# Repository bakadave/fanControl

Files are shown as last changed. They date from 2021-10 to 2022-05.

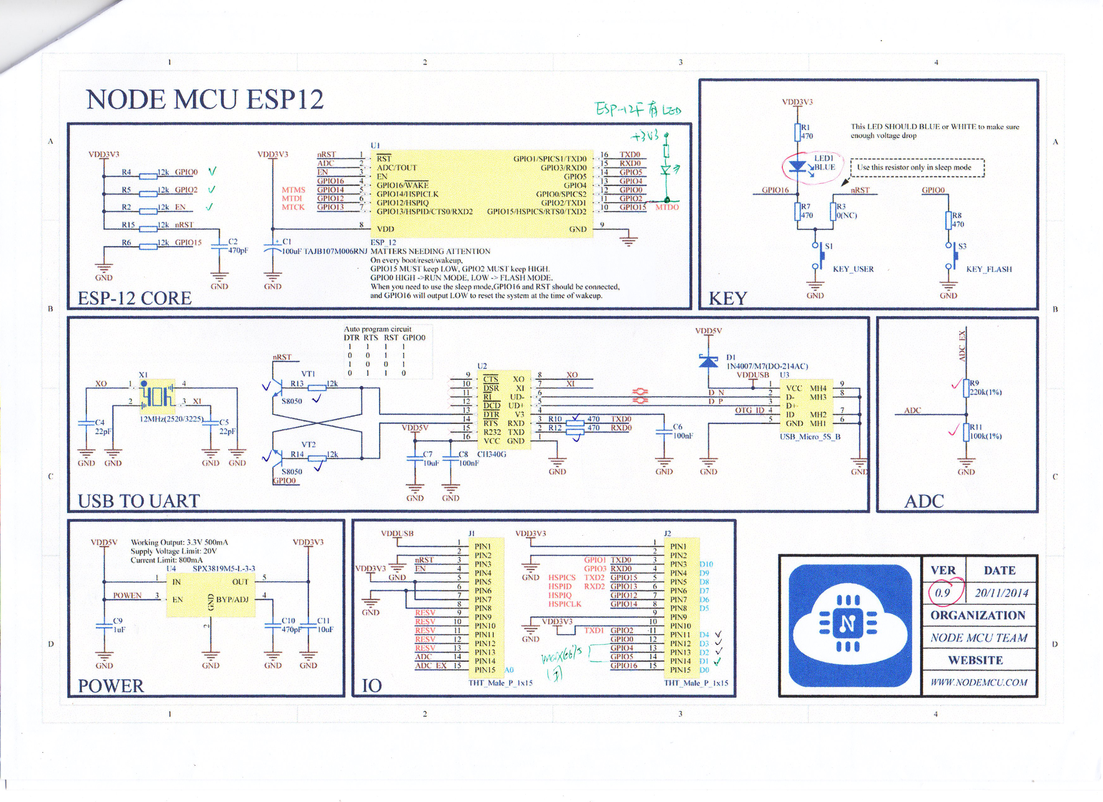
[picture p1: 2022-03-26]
PCB/fanControl/notes/esp12e-devkit-v2-xiaolaba-schematic_3.jpg

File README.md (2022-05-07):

# fanControl readme

## EEPROM memory map

| memory location | data type | Description|
| --- | --- | --- |
| 1 | bool | WiFi on |
| 2 | bool | 5V PSU |
| 3 | bool | USB sense |
| 4 | float | cal_a |
| 5 |  | cal_a |
| 6 |  | cal_a |
| 7 |  | cal_a |
| 8 | float | cal_b |
| 9 |  | cal_b |
| 10 | | cal_b |
| 11 | | cal_b |
| 12 | char[16] | hostname |
| 13 | | hostname |
| 14 | | hostname |
| 15 | | hostname |
| 16 | | hostname |
| 17 | | hostname |
| 18 | | hostname |
| 19 | | hostname |
| 20 | | hostname |
| 21 | | hostname |
| 22 | | hostname |
| 23 | | hostname |
| 24 | | hostname |
| 25 | | hostname |
| 26 | | hostname |
| 27 | | hostname |
| 28 | N/A | unused |
| 29 | N/A | unused |
| 30 | N/A | unused |
| 31 | N/A | unused |
| 32 | N/A | unused |

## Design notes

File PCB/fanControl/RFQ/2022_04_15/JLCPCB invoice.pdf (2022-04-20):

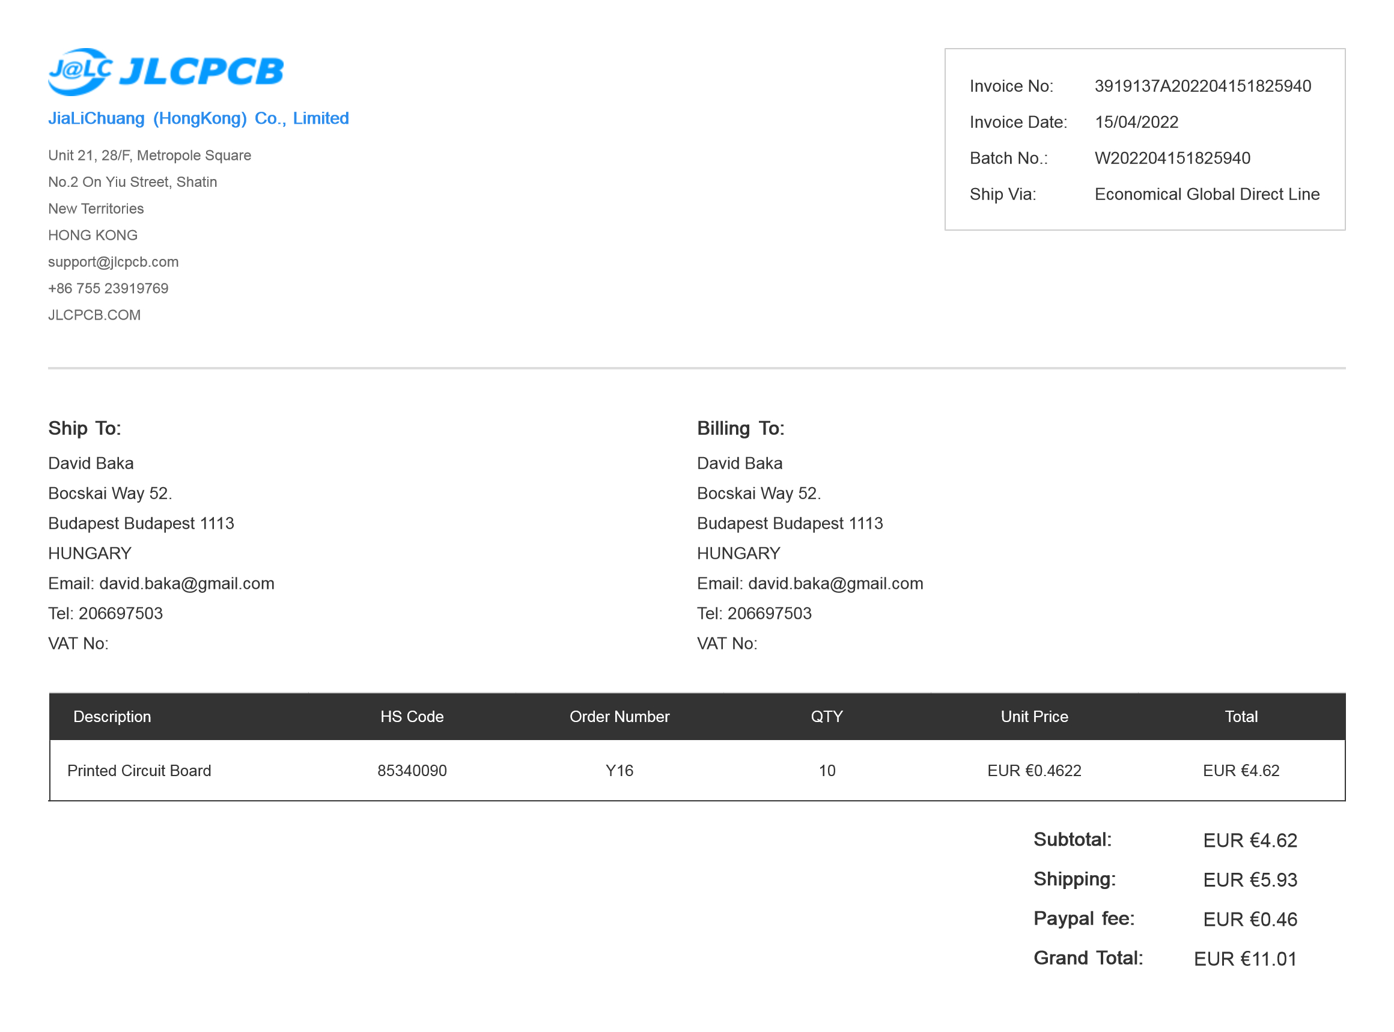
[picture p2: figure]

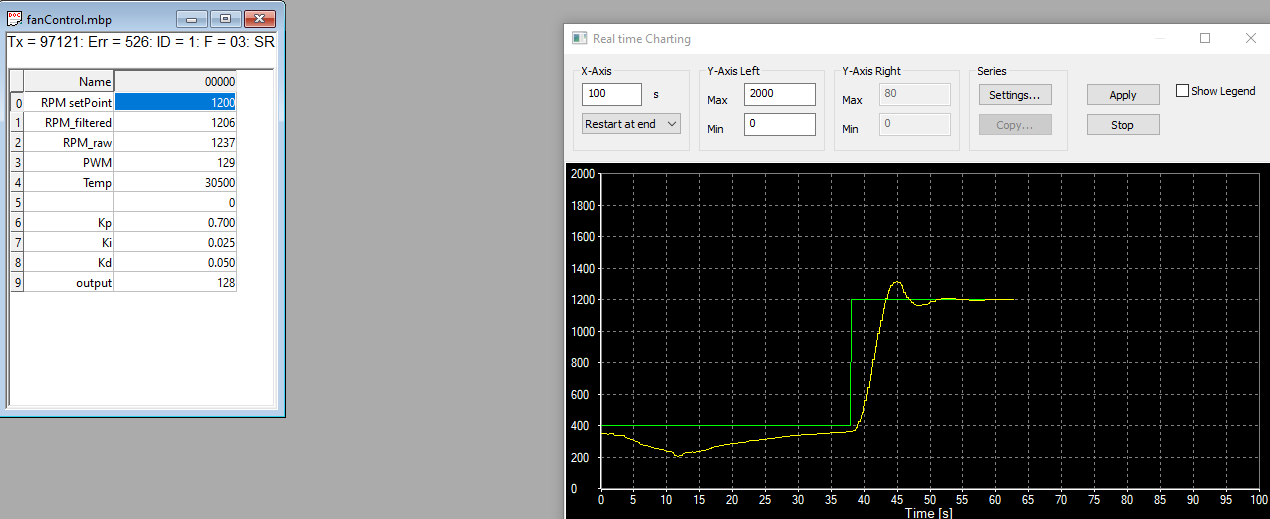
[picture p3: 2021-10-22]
notes/Screenshot_8.png

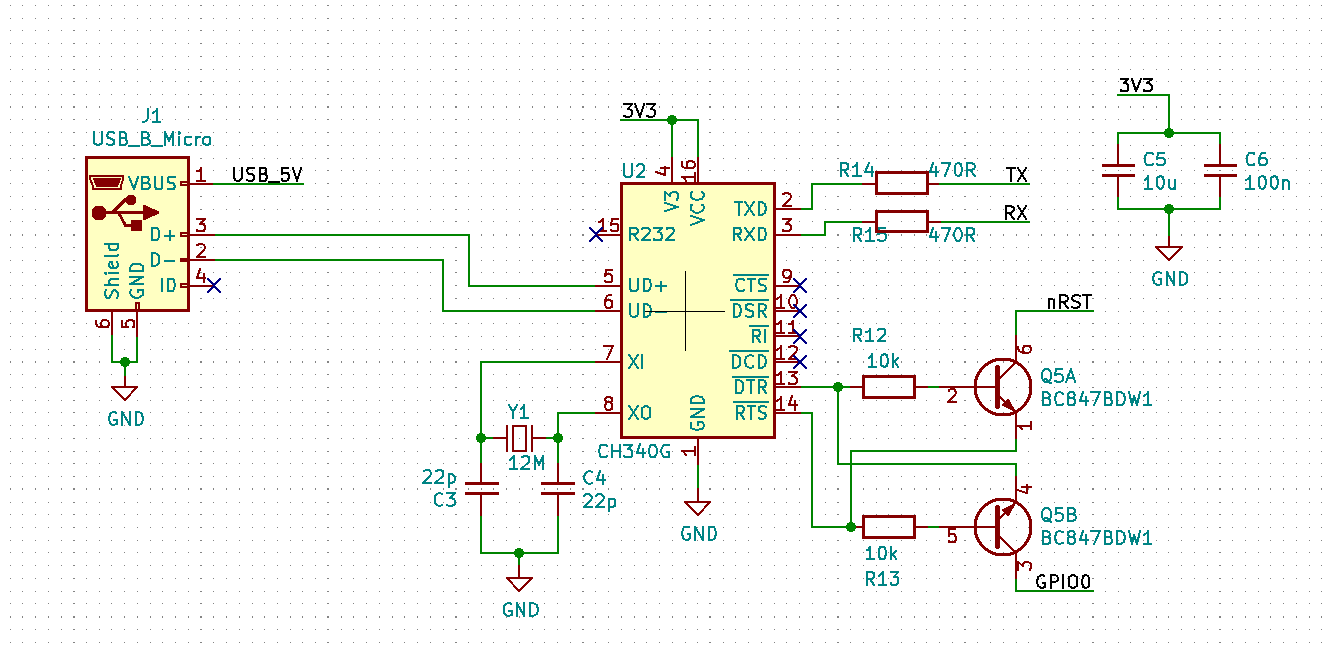
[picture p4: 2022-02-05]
PCB/fanControl/notes/CH340G.png

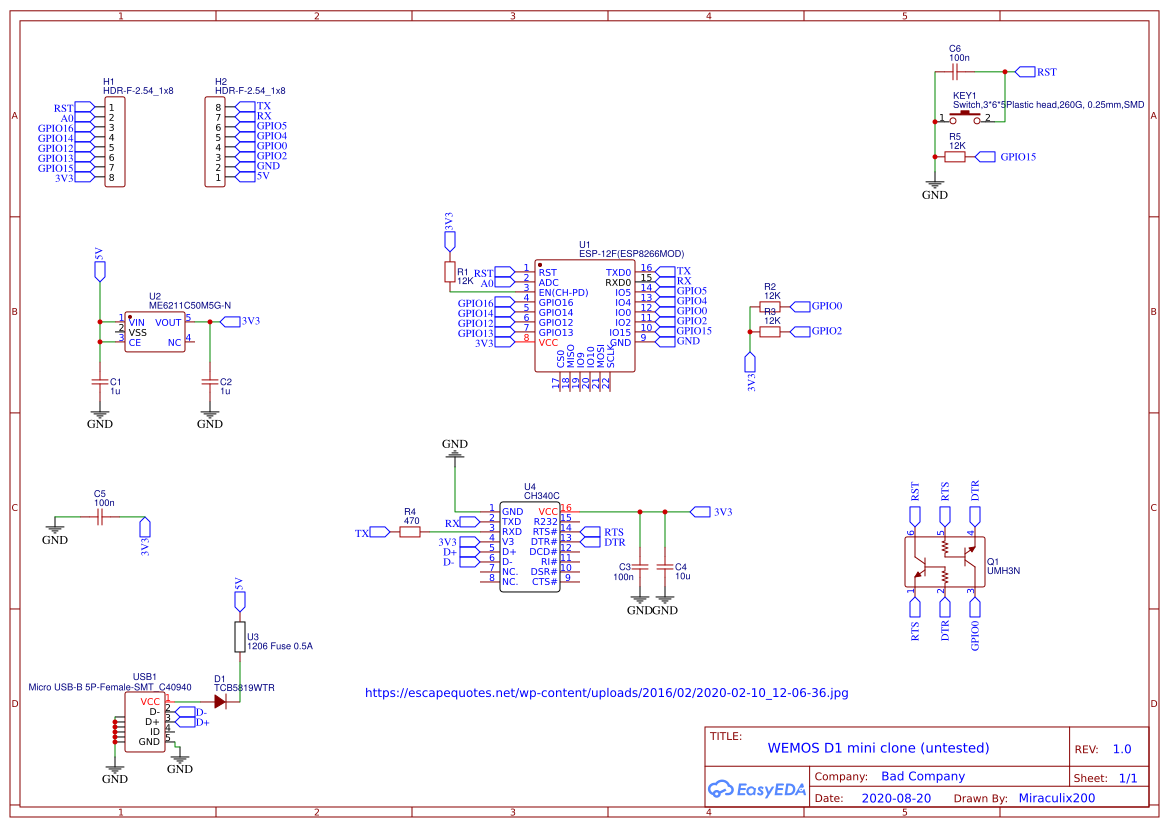
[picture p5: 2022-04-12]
PCB/fanControl/notes/Wemos D1 Mini.png

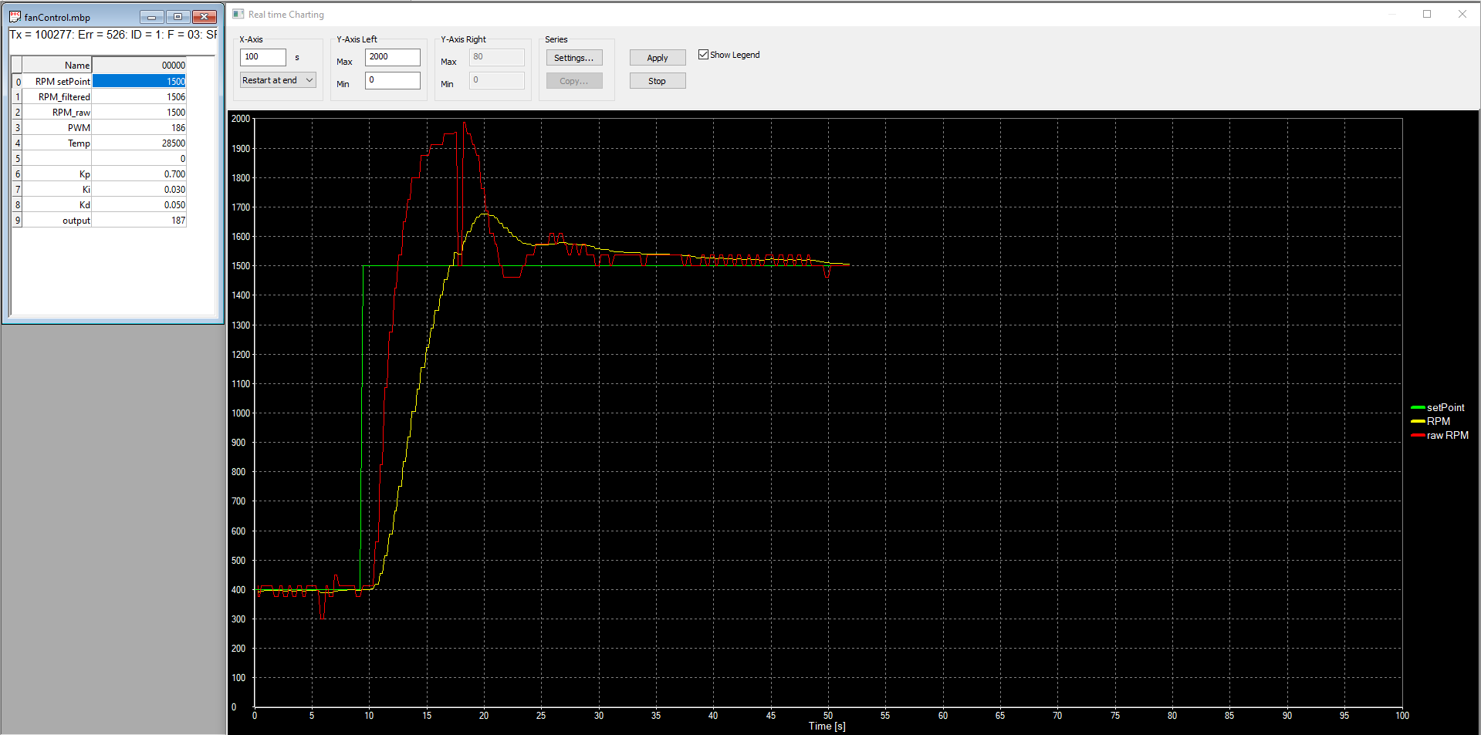
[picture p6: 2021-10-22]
notes/Screenshot_1.png

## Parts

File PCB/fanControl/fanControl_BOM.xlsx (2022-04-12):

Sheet: fanControl_BOM
Reference | Quantity | Value | Footprint | Datasheet | LCSC | MPN | Manufacturer | Supplier | URL | LCSC order quant | # available | 5
C1 C3 | 2 | 22p | agro-footprint:CAP_0805 | https://datasheet.lcsc.com/lcsc/2006151142_YAGEO-CC0805FRNPO9BN220_C541515.pdf | C541515 | CC0805FRNPO9BN220 | Yageo | LCSC |  | 10 | 10
C12 | 1 | 10u 10V | Capacitor_Tantalum_SMD:CP_EIA-3216-18_Kemet-A_Pad1.58x1.35mm_HandSolder | https://datasheet.lcsc.com/lcsc/2011031906_KEMET-T529P106M010AAE200_C696821.pdf | C696821 | T529P106M010AAE200 | KEMET | LCSC |  | 5 | 5
C2 | 1 | 10n 50V | agro-footprint:CAP_0805 | https://datasheet.lcsc.com/lcsc/2005262134_YAGEO-CC0805JKNPO9BN103_C527201.pdf | C527201 | CC0805JKNPO9BN103 | Yageo | LCSC |  | 5 | 4
C4 | 1 | 47u | Capacitor_THT:C_Radial_D6.3mm_H11.0mm_P2.50mm |  |  |  |  | Ã rwill | https://arwill.hu/termekek/passziv-alkatreszek/kondenzatorok/elektrolit-85c-105c/47uf-50v-elektrolit-kondenzator-974067/ | 5
C5 | 1 | 10u | agro-footprint:CAP_0805 | https://datasheet.lcsc.com/lcsc/1810311438_YAGEO-CC0805ZKY5V6BB106_C88484.pdf | C88484 | CC0805ZKY5V6BB106 | Yageo | LCSC |  | 5 | 49
C6 C7 C10 C11 | 4 | 100n | agro-footprint:CAP_0805 | https://datasheet.lcsc.com/lcsc/1810101813_YAGEO-CC0805KRX7R9BB104_C49678.pdf | C49678 | CC0805KRX7R9BB104 | Yageo | LCSC |  | 20 | 47
C8 | 1 | 470u | Capacitor_THT:C_Radial_D8.0mm_H11.5mm_P3.50mm |  |  |  |  | Ã rwill | https://arwill.hu/termekek/passziv-alkatreszek/kondenzatorok/elektrolit-85c-105c/470uf-16v-elektrolit-kondenzator-229671/ | 5 | 7
C9 | 1 | 100u | Capacitor_SMD:C_1206_3216Metric | https://datasheet.lcsc.com/lcsc/2006191032_YAGEO-CC1206MKX5R5BB107_C110048.pdf | C110048 | CC1206MKX5R5BB107 | Yageo | LCSC |  | 5 | 5
D1 | 1 | SMCJ36CA | Diode_SMD:D_SMC | https://datasheet.lcsc.com/lcsc/2110190930_BOURNS-SMCJ36CA_C2831485.pdf | C2831485 | SMCJ36CA | Bourns | LCSC |  | 5 | 4
D2 | 1 | BZX84C10L | Diode_SMD:D_SOT-23_ANK | https://datasheet.lcsc.com/lcsc/1810301517_onsemi-BZX84C10LT1G_C82476.pdf | C82476 | BZX84C10LT1G | onsemi | LCSC |  | 5 | 9
D3 D5 | 2 | MMSZ3V0 | Diode_SMD:D_SOD-123 | https://datasheet.lcsc.com/lcsc/1807270934_Tak-Cheong-MMSZ3V0CW_C248751.pdf | C248751 | MMSZ3V0CW | Tak Cheong | LCSC |  | 10 | 48
D4 | 1 | BZX84C6V8L | Diode_SMD:D_SOT-23_ANK | https://datasheet.lcsc.com/lcsc/1810301513_onsemi-BZX84C6V8LT1G_C90848.pdf | C90848 | BZX84C6V8LT1G | onsemi | LCSC |  | 5 | 9
D6 | 1 | RB160M | Diode_SMD:D_SOD-123 | https://datasheet.lcsc.com/lcsc/1810131621_ROHM-Semicon-RB160M-40TR_C123003.pdf | C123003 | RB160MM-40TR | Rohm Semiconductor | LCSC |  | 5 | 4
D7 | 1 | 10BQ015 | Diode_SMD:D_SMB | https://datasheet.lcsc.com/lcsc/2001101209_Vishay-Intertech-VS-10BQ015-M3-5BT_C413466.pdf | C413466 | VS-10BQ015-M3/5BT | Vishay | LCSC |  | 5 | 4
D8 | 1 | LED | agro-footprint:LED_0805 | https://datasheet.lcsc.com/lcsc/1811131731_Everlight-Elec-17-215-BHC-AP1Q2-3T_C131208.pdf | C131208 | 17-215/BHC-AP1Q2/3T | Everlight Elec | LCSC |  | 5 | 10
J1 | 1 | USB_B_Micro | Connector_USB:USB_Micro-B_Molex-105017-0001 | https://datasheet.lcsc.com/lcsc/1811131824_MOLEX-1050170001_C136000.pdf | C136000 | 1050170001 | Molex | LCSC |  | 5 | 4
J2 | 1 | Barrel_Jack_Switch | fanControl:BarrelJack_Wuerth_6941xx301002 |  |  |  |  | Ã rwill | https://arwill.hu/termekek/csatlakozok/tap/dc/dc-tap-aljzat-5-5-2-1-586196/ | 5
L1 | 1 | 470u | Inductor_THT:L_Radial_D10.5mm_P5.00mm_Abacron_AISR-01 |  |  |  |  | Ã rwill | https://arwill.hu/termekek/passziv-alkatreszek/induktivitasok/radialis/470uh-1-2a-induktivitas-659003/ | 5
Q1 | 1 | FDD4243 | fanControl:TO-252-2_TabPin5 | https://datasheet.lcsc.com/lcsc/2007231308_VBsemi-Elec-FDD4243_C709958.pdf | C709958 | FDD4243 | VBsemi Elec | LCSC |  | 5 | 4
Q2 Q5 | 2 | BSS169 | Package_TO_SOT_SMD:SOT-23 | https://datasheet.lcsc.com/lcsc/1810261812_Infineon-Technologies-BSS169H6327_C83053.pdf | C83053 | BSS169H6327 | Infineon | LCSC |  | 10 | 7
Q4 | 1 | BC847BDW1 | Package_TO_SOT_SMD:SOT-363_SC-70-6 | https://datasheet.lcsc.com/lcsc/1810010214_onsemi-BC847BDW1T1G_C82368.pdf | C82368 | BC847BDW1T1G | onsemi | LCSC |  | 5 | 9
Q6 | 1 | BRCS4484 | fanControl:BRCS4484 | https://datasheet.lcsc.com/lcsc/2012021739_Foshan-Blue-Rocket-Elec-BRCS4484SC_C914060.pdf | C914060 | BRCS4484SC | Foshan Blue Rocket Elec | LCSC |  | 5 | 5
R1 R2 R14 R20 R29 R31 R32 | 7 | 1k | agro-footprint:RES_0805 | https://datasheet.lcsc.com/lcsc/1810010217_YAGEO-RC0805JR-071KL_C100046.pdf | C100046 | RC0805JR-071KL | Yageo | LCSC |  | 35 | 98
R12 R13 R26 R27 R28 | 5 | 470R | agro-footprint:RES_0805 | https://datasheet.lcsc.com/lcsc/1810162110_YAGEO-RC0805JR-07470RL_C114747.pdf | C114747 | RC0805JR-07470RL | Yageo | LCSC |  | 25 | 95
R16 | 1 | 3k6 | agro-footprint:RES_0805 | https://datasheet.lcsc.com/lcsc/1810311331_YAGEO-AC0805JR-073K6L_C229201.pdf | C229201 | AC0805JR-073K6L | Yageo | LCSC |  | 5 | 49
R17 | 1 | 6k8 | agro-footprint:RES_0805 | https://datasheet.lcsc.com/lcsc/1810311425_YAGEO-RC0805JR-076K8L_C137409.pdf | C137409 | RC0805JR-076K8L | Yageo | LCSC |  | 5 | 99
R18 | 1 | 1k1 1% | agro-footprint:RES_0805 | https://datasheet.lcsc.com/lcsc/1810241428_YAGEO-RC0805FR-071K1L_C185294.pdf | C185294 | RC0805FR-071K1L | Yageo | LCSC |  | 5 | 100
R19 | 1 | 3k3 1% | agro-footprint:RES_0805 | https://datasheet.lcsc.com/lcsc/1810311430_YAGEO-RC0805FR-073K3L_C114531.pdf | C114531 | RC0805FR-073K3L | Yageo | LCSC |  | 5 | 100
R3 R15 R30 R33 | 4 | 100k | agro-footprint:RES_0805 | https://datasheet.lcsc.com/lcsc/1810241513_YAGEO-RC0805JR-07100KL_C100049.pdf | C100049 | RC0805JR-07100KL | Yageo | LCSC |  | 20 | 99
R4 R7 R8 R10 R11 R21 R22 R23 R24 R25 | 10 | 10k | agro-footprint:RES_0805 | https://datasheet.lcsc.com/lcsc/1810171610_YAGEO-RC0805JR-0710KL_C100047.pdf | C100047 | RC0805JR-0710KL | Yageo | LCSC |  | 50 | 93
R5 | 1 | 2k2 | agro-footprint:RES_0805 | https://datasheet.lcsc.com/lcsc/1810311425_YAGEO-RC0805JR-072K2L_C114237.pdf | C114237 | RC0805JR-072K2L | Yageo | LCSC |  | 5 | 99
R6 | 1 | 4k7 | agro-footprint:RES_0805 | https://datasheet.lcsc.com/lcsc/1810010620_YAGEO-RC0805JR-074K7L_C105427.pdf | C105427 | RC0805JR-074K7L | Yageo | LCSC |  | 5 | 99
R9 | 1 | 47k | agro-footprint:RES_0805 | https://datasheet.lcsc.com/lcsc/1810311310_YAGEO-RC0805JR-0747KL_C131051.pdf | C131051 | RC0805JR-0747KL | Yageo | LCSC |  | 5 | 100
RV1 | 1 | 1k | fanControl:pot | https://datasheet.lcsc.com/lcsc/1810170727_HDK-Hokuriku-Elec-Industry-VG039NCHXTB102_C128543.pdf | C128543 | VG039NCHXTB102 | HDK | LCSC |  | 5 | 9
U2 | 1 | CH340B | Package_SO:SOIC-16_3.9x9.9mm_P1.27mm | https://www.mpja.com/download/35227cpdata.pdf | C81010 | CH340B | WCH | LCSC |  | 5 | 2
U3 | 1 | LM2575BT-ADJ | Package_TO_SOT_THT:TO-220-5_Vertical | https://datasheet.lcsc.com/lcsc/1912111437_HGSEMI-LM2575T-ADJ_C434579.pdf | C434579 | LM2575T-ADJ | HGSEMI | LCSC |  | 5 | 5
U4 | 1 | LM1117 | Package_TO_SOT_SMD:SOT-223-3_TabPin2 | https://datasheet.lcsc.com/lcsc/1809301716_Texas-Instruments-LM1117IMPX-3-3-NOPB-_C23984.pdf | C23984 | LM1117IMPX-3.3/NOPB | Texas Instruments | LCSC |  | 5 | 4
U5 | 1 | ESP-12E | kicad-ESP8266:ESP-12E | http://l0l.org.uk/2014/12/esp8266-modules-hardware-guide-gotta-catch-em-all/ | C89297 | ESP-12E | Ai-Thinker | LCSC |  | 5 | 4
Y1 | 1 | 12M | Crystal:Crystal_SMD_3225-4Pin_3.2x2.5mm | https://datasheet.lcsc.com/lcsc/1912111437_JGHC-S3212000101080_C390763.pdf | C390763 | S3212000101080 | JGHC | LCSC |  | 5

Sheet: SMT selected
Comment | Designator | Footprint | JLCPCB Part #
10k | R7,R8,R13 | agro-footprint:RES_0805 | C17414
6k8 | R3,R12 | agro-footprint:RES_0805 | C17772
100n | C10,C11 | agro-footprint:CAP_0805 | C49678
10u10V | C12 | Capacitor_Tantalum_SMD:CP_EIA-3216-18_Kemet-A_Pad1.58x1.35mm_HandSolder | C7171
100u | C9 | Capacitor_SMD:C_1206_3216Metric | C15008
2k | R4 | agro-footprint:RES_0805 | C17604
47k | R11 | agro-footprint:RES_0805 | C17713
1k | R1,R9,R20,R29,R30,R32,R18 | agro-footprint:RES_0805 | C17513
3k31% | R19 | agro-footprint:RES_0805 | C26010
100k | R2,R10,R31,R33 | agro-footprint:RES_0805 | C149504
470R | R26,R28 | agro-footprint:RES_0805 | C17710

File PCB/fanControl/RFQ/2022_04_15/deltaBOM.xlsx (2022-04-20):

Reference | Quantity | Value | Footprint | Datasheet | LCSC | MPN | Manufacturer | Supplier | RMK | # needed | # available | delta
C10 C12 | 2 | 10u 10V | Capacitor_Tantalum_SMD:CP_EIA-3216-18_Kemet-A_Pad1.58x1.35mm_HandSolder | https://datasheet.lcsc.com/lcsc/2011031906_KEMET-T529P106M010AAE200_C696821.pdf | C696821 | T529P106M010AAE200 | KEMET | LCSC |  | 8 | 5 | -3
C2 C13 C14 | 3 | 10n 50V | agro-footprint:CAP_0805 | https://datasheet.lcsc.com/lcsc/2005262134_YAGEO-CC0805JKNPO9BN103_C527201.pdf | C527201 | CC0805JKNPO9BN103 | Yageo | LCSC |  | 12 | 4 | -8
D3 D5 | 2 | BZX84C3V3 | Diode_SMD:D_SOT-23_ANK | https://datasheet.lcsc.com/lcsc/1810301522_onsemi-BZX84C3V3LT1G_C82473.pdf | C82473 | BZX84C3V3LT1G | onsemi | LCSC |  | 8 | #N/A | -8
D9 | 1 | CUS10S30 | Diode_SMD:D_SOD-323_HandSoldering | https://datasheet.lcsc.com/lcsc/1810181811_TOSHIBA-CUS10S30-H3F_C146335.pdf | C146335 | CUS10S30,H3F | Toshiba | LCSC |  | 4 | #N/A | -4
Q2 Q8 | 2 | BSS84 | Package_TO_SOT_SMD:SOT-23 | https://datasheet.lcsc.com/lcsc/1808281643_Infineon-Technologies-BSS84PH6327_C152212.pdf | C152212 | BSS84PH6327 | Infineon | LCSC |  | 8 | #N/A | -8
Q4 Q5 Q7 Q9 Q10 | 5 | BC847B | Package_TO_SOT_SMD:SOT-23 | https://datasheet.lcsc.com/lcsc/1810301520_onsemi-BC847BLT1G_C94393.pdf | C94393 | BC847BLT1G | onsemi | LCSC |  | 20 | #N/A | -20
Q6 | 1 | DMP4065 | Package_TO_SOT_SMD:SOT-23 | https://datasheet.lcsc.com/lcsc/1912111437_Diodes-Incorporated-DMP4065S-7_C182476.pdf | C182476 | DMP4065S-7 | Diodes Incorporated | LCSC |  | 4 | #N/A | -4
R2 R4 R14 R40 | 4 | 22k | agro-footprint:RES_0805 | https://datasheet.lcsc.com/lcsc/1810311430_YAGEO-RC0805FR-0722KL_C114565.pdf | C114565 | RC0805FR-0722KL | Yageo | LCSC | 1% | 16 | #N/A | -16
R36 | 1 | 6k8 | agro-footprint:RES_0805 | https://datasheet.lcsc.com/lcsc/1810311431_YAGEO-RC0805FR-076K8L_C114550.pdf | C114550 | RC0805FR-076K8L | Yageo | LCSC | 1% | 4 | #N/A | -4
R6 R10 R11 | 3 | 4k7 | agro-footprint:RES_0805 | https://datasheet.lcsc.com/lcsc/1810161341_YAGEO-RC0805FR-074K7L_C60816.pdf | C60816 | RC0805FR-074K7L | Yageo | LCSC | 1% | 12 | #N/A | -12
U2 | 1 | CH340B | Package_SO:SOIC-16_3.9x9.9mm_P1.27mm | https://www.mpja.com/download/35227cpdata.pdf | C81010 | CH340B | WCH | LCSC |  | 4 | 2 | -2

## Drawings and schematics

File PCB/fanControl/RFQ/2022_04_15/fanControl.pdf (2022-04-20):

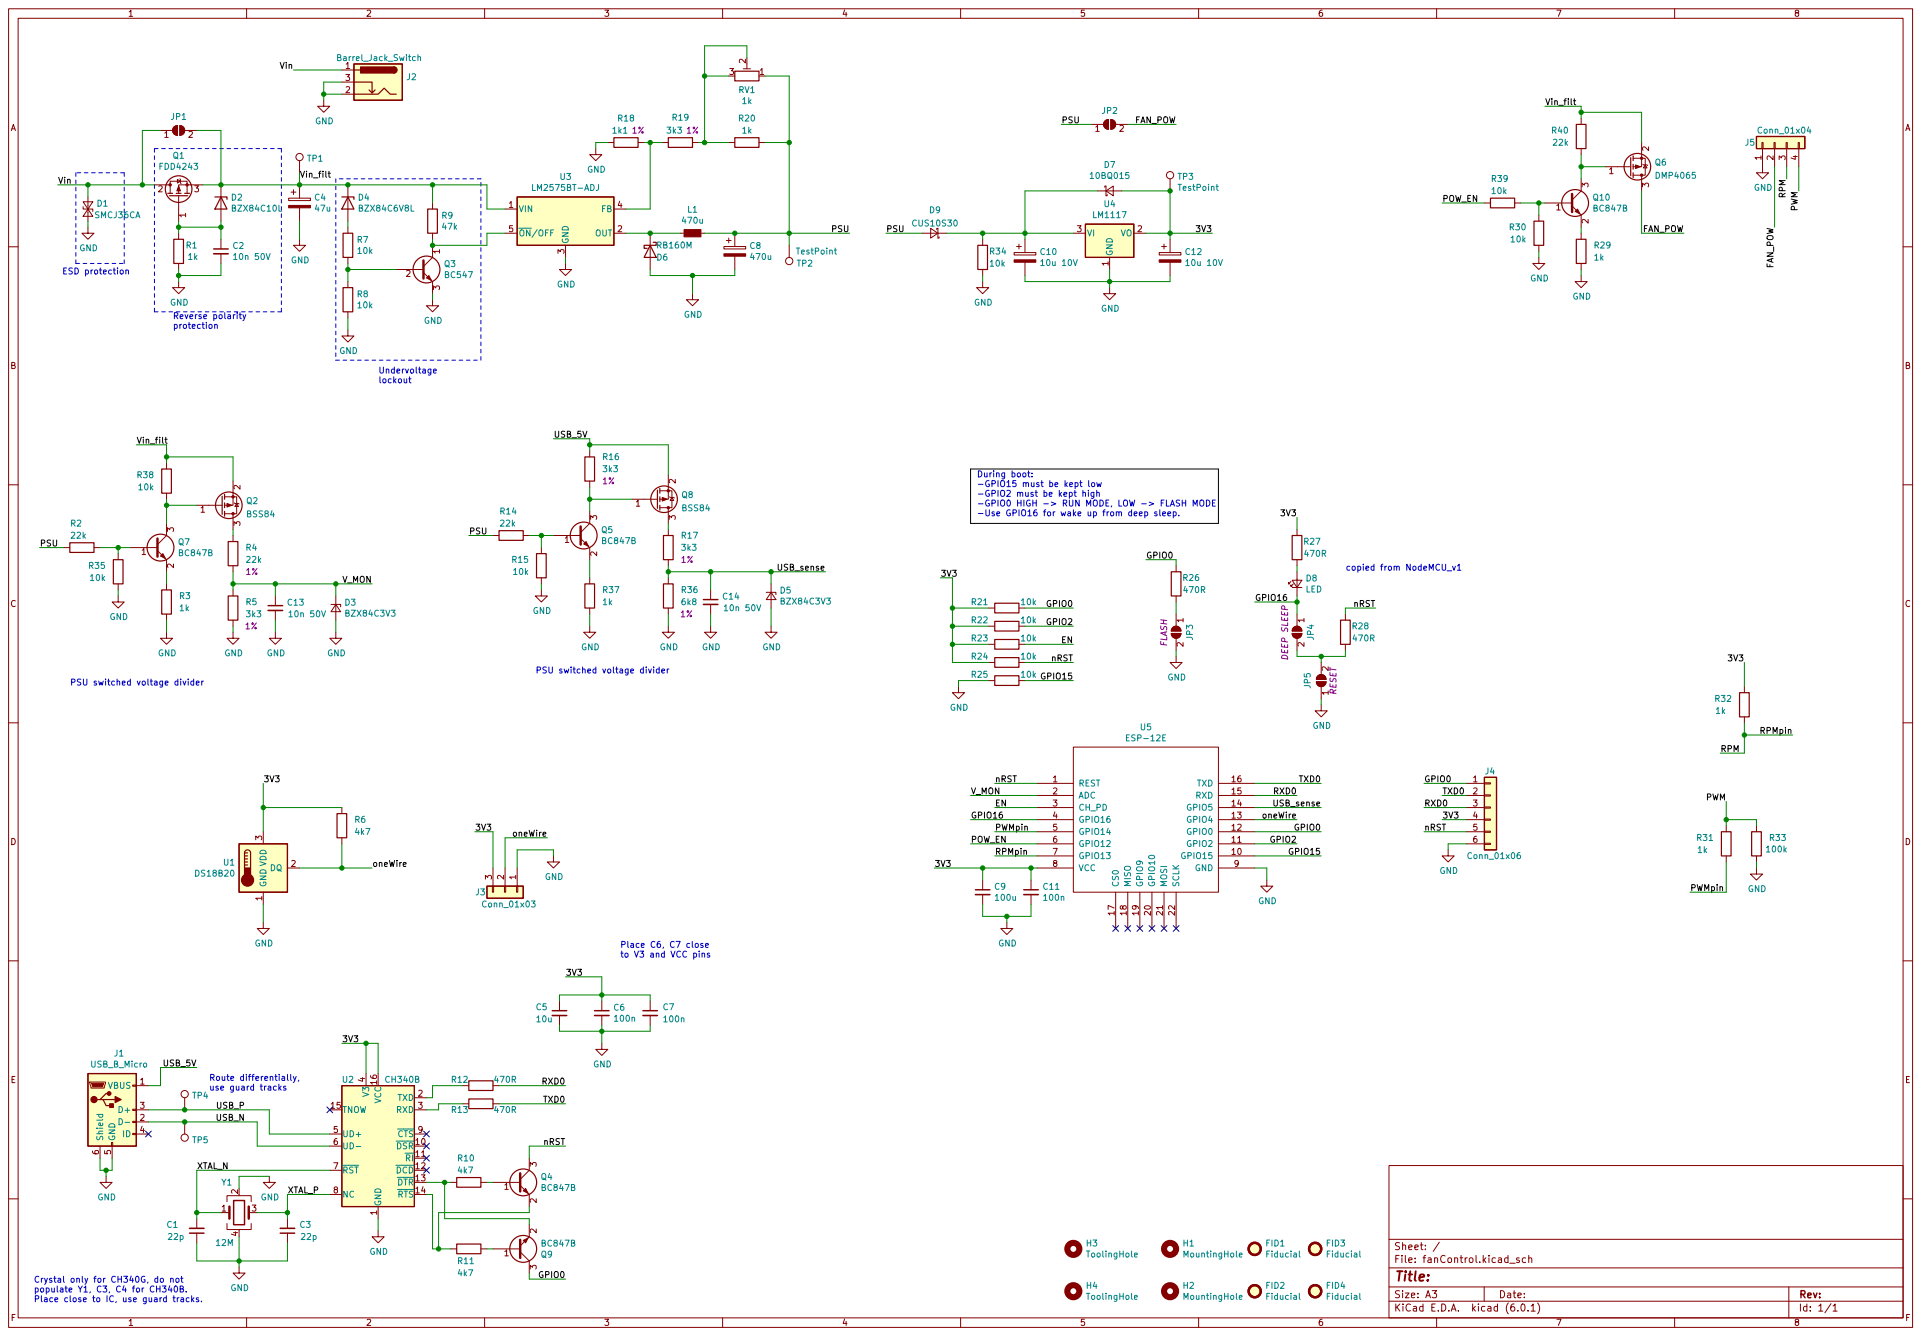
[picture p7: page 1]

During boot:
-GPIO15 must be kept low
-GPIO2 must be kept high
-GPIO0 HIGH -> RUN MODE, LOW -> FLASH MODE
-Use GPIO16 for wake up from deep sleep.

PSU switched voltage divider

to V3 and VCC pins

1 ~{DSR}10 ~{RI}11 ~{DCD}12 ~{DTR}13 ~{RTS}14 TNOW 15 VCC 16 TXD 2 RXD 3 V3

4 UD+ 5 UD- 6 ~{RST} 7 NC 8 ~{CTS}9 U2 CH340B

File: fanControl.kicad_sch Sheet: / GND

Crystal only for CH340G, do not
populate Y1, C3, C4 for CH340B.
Place close to IC, use guard tracks.

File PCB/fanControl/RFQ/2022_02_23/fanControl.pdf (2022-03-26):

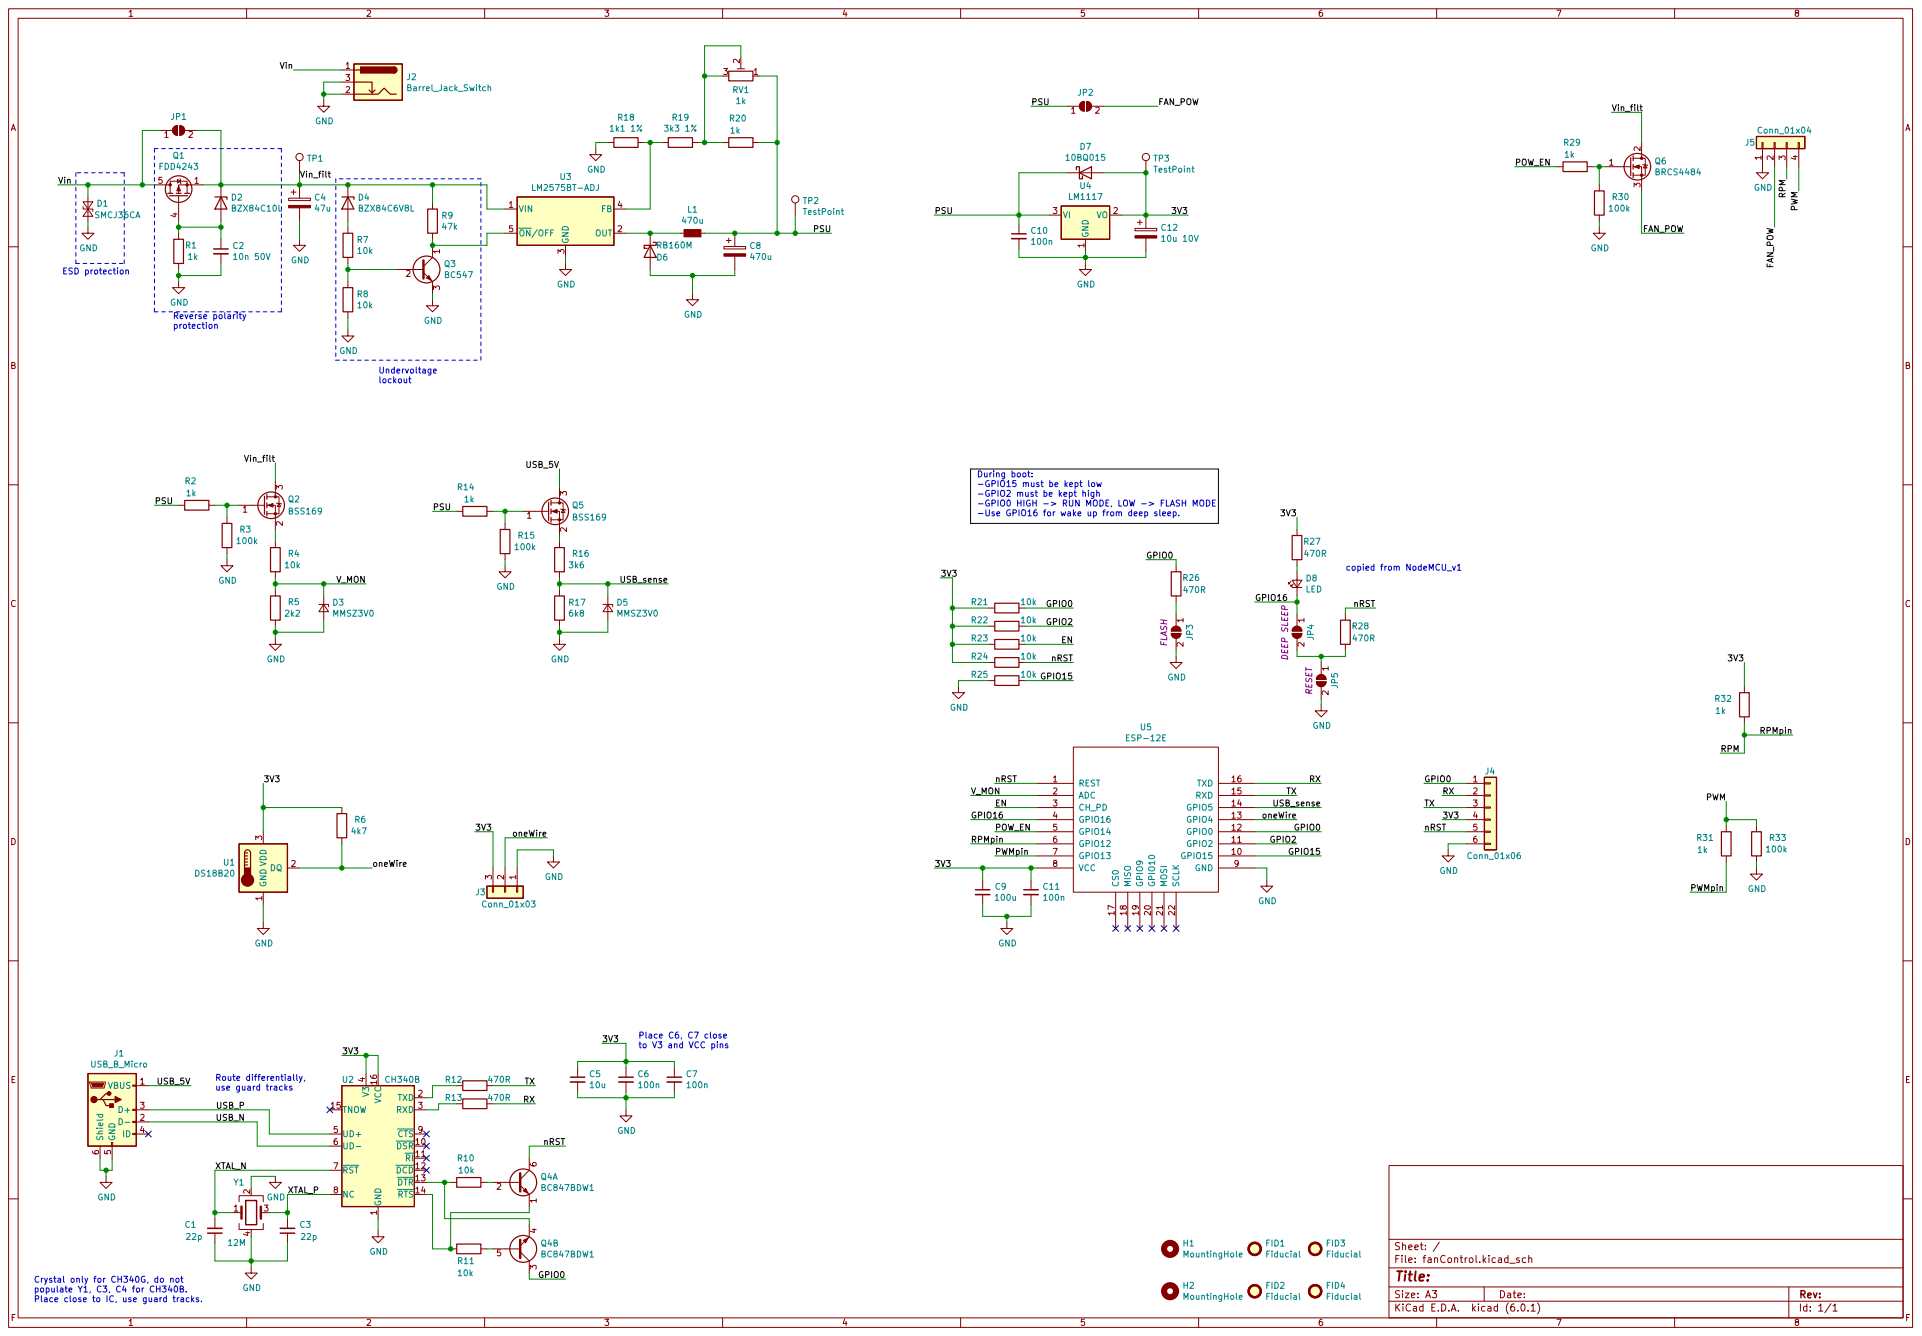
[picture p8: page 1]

During boot:
-GPIO15 must be kept low
-GPIO2 must be kept high
-GPIO0 HIGH -> RUN MODE, LOW -> FLASH MODE
470R GND

-Use GPIO16 for wake up from deep sleep. Place C6, C7 close

to V3 and VCC pins

4 UD+ 5 UD- 6 ~{RST} 7 NC 8 ~{CTS}9 U2 CH340B VBUS 1 D- 2 D+ 3

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

File: fanControl.kicad_sch Sheet: / GND

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

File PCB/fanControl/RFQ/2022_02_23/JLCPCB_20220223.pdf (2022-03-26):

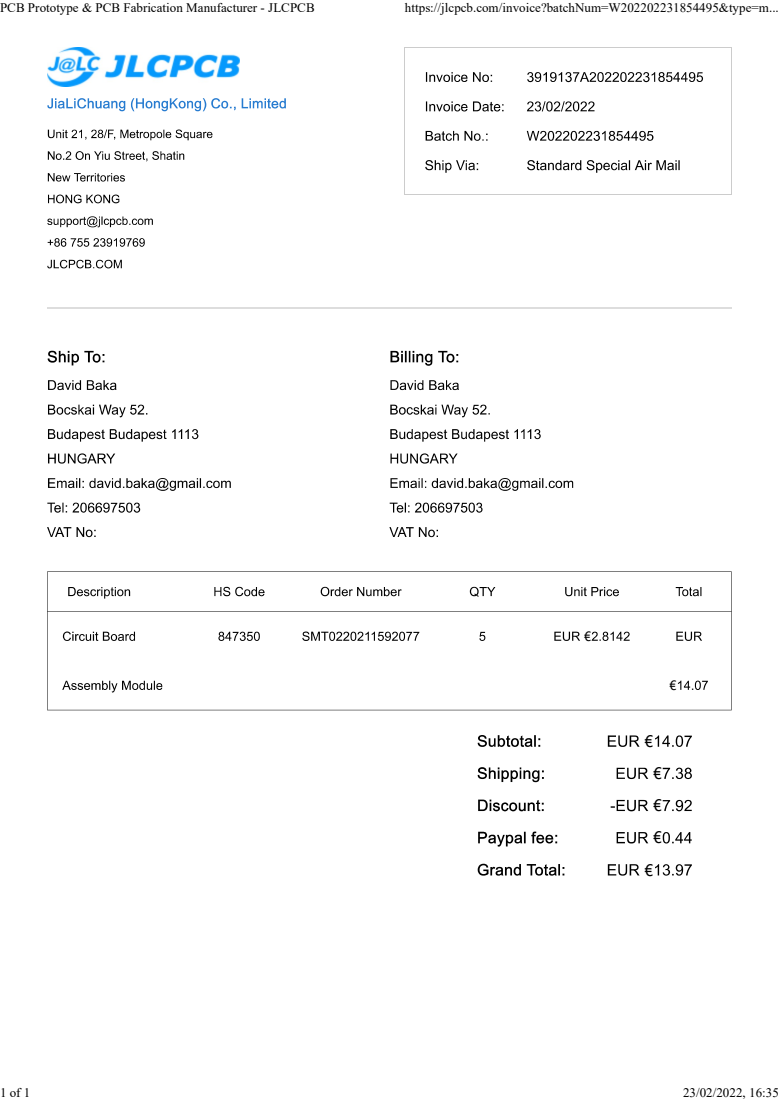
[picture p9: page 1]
PCB Prototype & PCB Fabrication Manufacturer - JLCPCB; https://jlcpcb.com/invoice?batchNum=W202202231854495&type=m...

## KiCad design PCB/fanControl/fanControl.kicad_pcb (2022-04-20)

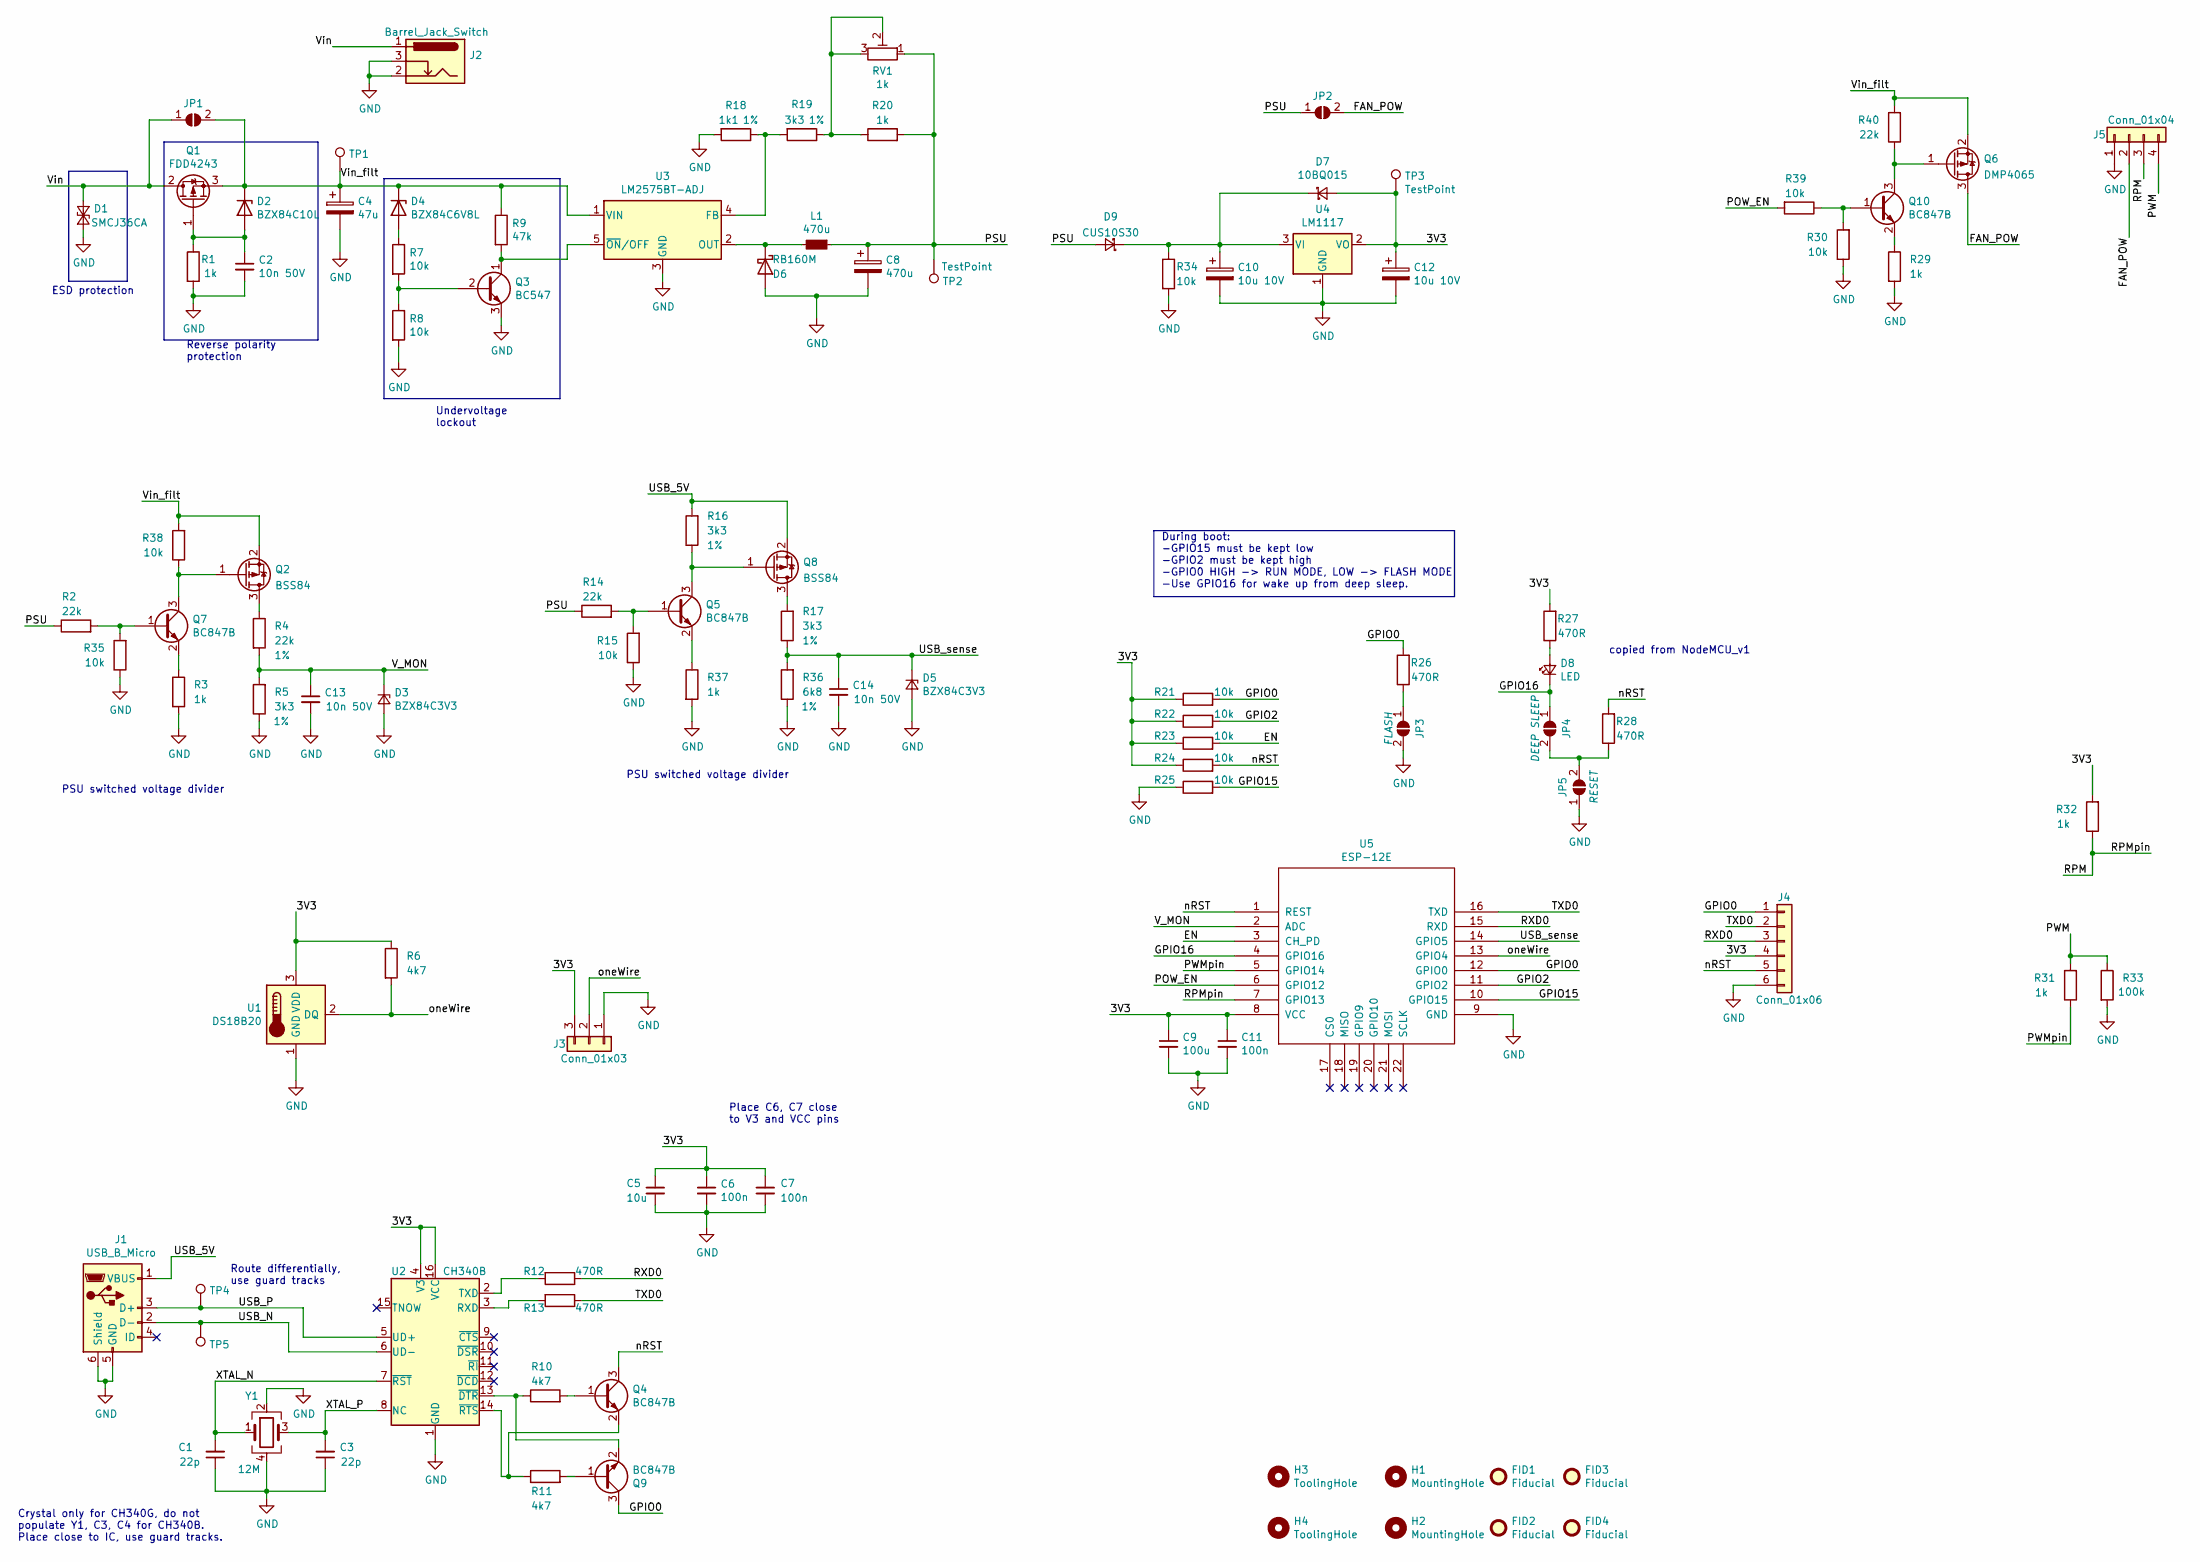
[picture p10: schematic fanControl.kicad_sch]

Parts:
C1, C3: 22p; CAP_0805; MPN CC0805FRNPO9BN220; LCSC C541515
C2, C13, C14: 10n 50V; CAP_0805; MPN CC0805JKNPO9BN103; LCSC C527201
C4: 47u; C_Radial_D6.3mm_H11.0mm_P2.50mm
C5: 10u; CAP_0805; MPN CC0805ZKY5V6BB106; LCSC C88484
C6, C7, C11: 100n; CAP_0805; MPN CC0805KRX7R9BB104; LCSC C49678
C8: 470u; C_Radial_D8.0mm_H11.5mm_P3.50mm
C9: 100u; C_1206_3216Metric; MPN CC1206MKX5R5BB107; LCSC C110048
C10, C12: 10u 10V; CP_EIA-3216-18_Kemet-A_Pad1.58x1.35mm_HandSolder; MPN T529P106M010AAE200; LCSC C696821
D1: SMCJ36CA; D_SMC; MPN SMCJ36CA; LCSC C2831485
D2: BZX84C10L; D_SOT-23_ANK; MPN BZX84C10LT1G; LCSC C82476
D3, D5: BZX84C3V3; D_SOT-23_ANK; MPN BZX84C3V3LT1G; LCSC C82473
D4: BZX84C6V8L; D_SOT-23_ANK; MPN BZX84C6V8LT1G; LCSC C90848
D6: RB160M; D_SOD-123; MPN RB160M-40TR; LCSC C123003
D7: 10BQ015; D_SMB; MPN VS-10BQ015-M3/5BT; LCSC C413466
D8: LED; LED_0805; MPN 17-215/BHC-AP1Q2/3T; LCSC C131208
D9: CUS10S30; D_SOD-323_HandSoldering; MPN CUS10S30,H3F; LCSC C146335
FID1, FID2, FID3, FID4: Fiducial; Fiducial_0.5mm_Mask1.5mm
H1, H2: MountingHole; MountingHole_3.2mm_M3
H3, H4: ToolingHole; JLC_toolinghole
J1: USB_B_Micro; USB_Micro-B_Molex-105017-0001; MPN 1050170001; LCSC C136000
J2: Barrel_Jack_Switch; BarrelJack_GCT_DCJ200-10-A_Horizontal; MPN 694106301002
J3: Conn_01x03; Molex_KK-254_AE-6410-03A_1x03_P2.54mm_Vertical
J4: Conn_01x06; PinHeader_1x06_P2.54mm_Vertical
J5: Conn_01x04; Molex_KK-254_AE-6410-04A_1x04_P2.54mm_Vertical
JP1, JP2, JP3, JP4, JP5: SolderJumper_2_Open; SolderJumper-2_P1.3mm_Open_TrianglePad1.0x1.5mm
L1: 470u; L_Radial_D10.5mm_P5.00mm_Abacron_AISR-01
Q1: FDD4243; TO-252-2; MPN FDD4243; LCSC C709958
Q2, Q8: BSS84; SOT-23; MPN BSS84PH6327; LCSC C152212
Q3: BC547; TO-92_Inline_Wide; MPN BC547B; LCSC C713613
Q4, Q5, Q7, Q9, Q10: BC847B; SOT-23; MPN BC847BLT1G; LCSC C94393
Q6: DMP4065; SOT-23; MPN DMP4065S-7; LCSC C182476
R1, R3, R20, R29, R31, R32, R37: 1k; RES_0805; MPN RC0805JR-071KL; LCSC C100046
R2, R4, R14, R40: 22k; RES_0805; MPN RC0805FR-0722KL; LCSC C114565
R5, R16, R17, R19: 3k3; RES_0805; MPN RC0805FR-073K3L; LCSC C114531
R6, R10, R11: 4k7; RES_0805; MPN RC0805FR-074K7L; LCSC C60816
R7, R8, R15, R21, R22, R23, R24, R25, R30, R34, R35, R38, R39: 10k; RES_0805; MPN RC0805JR-0710KL; LCSC C100047
R9: 47k; RES_0805; MPN RC0805JR-0747KL; LCSC C131051
R12, R13, R26, R27, R28: 470R; RES_0805; MPN RC0805JR-07470RL; LCSC C114747
R18: 1k1; RES_0805; MPN RC0805FR-071K1L; LCSC C185294
R33: 100k; RES_0805; MPN RC0805JR-07100KL; LCSC C100049
R36: 6k8; RES_0805; MPN RC0805FR-076K8L; LCSC C114550
RV1: 1k; pot; MPN VG039NCHXTB102; LCSC C128543
TP1, TP2, TP3, TP4, TP5: TestPoint; TestPoint_Pad_D1.0mm
U1: DS18B20; TO-92_Inline_Wide; MPN DS18B20+; LCSC C9753
U2: CH340B; SOIC-16_3.9x9.9mm_P1.27mm; MPN CH340B; LCSC C81010
U3: LM2575BT-ADJ; TO-220-5_Vertical; MPN LM2575T-ADJ; LCSC C434579
U4: LM1117; SOT-223-3_TabPin2; MPN LM1117IMPX-3.3/NOPB; LCSC C23984
U5: ESP-12E; MPN ESP-12E; LCSC C89297
Y1: 12M; Crystal_SMD_3225-4Pin_3.2x2.5mm; MPN S3212000101080; LCSC C390763

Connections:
/3V3: C5.1, C6.1, C7.1, C9.1, C11.1, C12.1, D7.2 (A), J3.3, J4.4, R6.1, R21.1, R22.1, R23.1, R24.1, R27.2, R32.2, TP3.1, U1.3 (VDD), U2.4 (V3), U2.16 (VCC), U4.2 (VO), U5.8 (VCC)
/EN: R23.2, U5.3 (CH_PD)
/FAN_POW: J5.2, JP2.2 (B), Q6.3 (D)
/GPIO0: J4.1, Q9.3 (C), R21.2, R26.2, U5.12 (GPIO0)
/GPIO2: R22.2, U5.11 (GPIO2)
/GPIO15: R25.2, U5.10 (GPIO15)
/GPIO16: D8.1 (K), JP4.1 (A), U5.4 (GPIO16)
/POW_EN: R39.2, U5.6 (GPIO12)
/PSU: C8.1, D9.2 (A), JP2.1 (A), L1.1, R2.1, R14.1, R20.2, RV1.1, TP2.1
/PWM: J5.4, R31.2, R33.1
/PWMpin: R31.1, U5.5 (GPIO14)
/RPM: J5.3, R32.1, U5.7 (GPIO13)
/RXD0: J4.3, R12.1, U5.15 (RXD)
/TXD0: J4.2, R13.1, U5.16 (TXD)
/USB_5V: J1.1 (VBUS), Q8.2 (S), R16.2
/USB_N: J1.2 (D-), TP5.1, U2.6 (UD-)
/USB_P: J1.3 (D+), TP4.1, U2.5 (UD+)
/USB_sense: C14.1, D5.1 (K), R17.1, R36.2, U5.14 (GPIO5)
/V_MON: C13.1, D3.1 (K), R4.2, R5.2, U5.2 (ADC)
/Vin: D1.1 (K), J2.1, JP1.1 (A), Q1.2 (D)
/Vin_filt: C4.1, D2.1 (K), D4.1 (K), JP1.2 (B), Q1.3 (S), Q2.2 (S), Q6.2 (S), R9.1, R38.2, R40.2, TP1.1, U3.1 (VIN)
/XTAL_N: C1.2, U2.7 (~RST), Y1.1
/XTAL_P: C3.2, U2.8 (NC), Y1.3
/nRST: J4.5, Q4.3 (C), R24.2, R28.2, U5.1 (REST)
/oneWire: J3.2, R6.2, U1.2 (DQ), U5.13 (GPIO4)
GND: C1.1, C2.2, C3.1, C4.2, C5.2, C6.2, C7.2, C8.2, C9.2, C10.2, C11.2, C12.2, C13.2, C14.2, D1.2 (A), D3.2 (A), D5.2 (A), D6.2 (A), J1.5 (GND), J1.6 (Shield), J2.2, J2.3, J3.1, J4.6, J5.1, JP3.2 (B), JP5.1 (A), Q3.3 (E), R1.2, R3.2, R5.1, R8.2, R15.1, R18.2, R25.1, R29.2, R30.1, R33.2, R34.2, R35.1, R36.1, R37.2, U1.1 (GND), U2.1 (GND), U3.3 (GND), U4.1 (GND), U5.9 (GND), Y1.2, Y1.4
unnamed: C2.1, D2.2 (A), Q1.1 (G), R1.1
unnamed: C10.1, D7.1 (K), D9.1 (K), R34.1, U4.3 (VI)
unnamed: D4.2 (A), R7.1
unnamed: D6.1 (K), L1.2, U3.2 (OUT)
unnamed: D8.2 (A), R27.1
unnamed: JP3.1 (A), R26.1
unnamed: JP4.2 (B), JP5.2 (B), R28.1
unnamed: Q2.1 (G), Q7.3 (C), R38.1
unnamed: Q2.3 (D), R4.1
unnamed: Q3.1 (C), R9.2, U3.5 (~ON/OFF)
unnamed: Q3.2 (B), R7.2, R8.1
unnamed: Q4.1 (B), R10.2
unnamed: Q4.2 (E), R11.1, U2.14 (~RTS)
unnamed: Q5.3 (C), Q8.1 (G), R16.1
unnamed: Q6.1 (G), Q10.3 (C), R40.1
unnamed: Q7.1 (B), R2.2, R35.2
unnamed: Q7.2 (E), R3.1
unnamed: Q9.1 (B), R11.2
unnamed: Q9.2 (E), R10.1, U2.13 (~DTR)
unnamed: R12.2, U2.2 (TXD)
unnamed: R13.2, U2.3 (RXD)
unnamed: Q5.1 (B), R14.2, R15.2
unnamed: Q8.3 (D), R17.2
unnamed: R18.1, R19.2, U3.4 (FB)
unnamed: R19.1, R20.1, RV1.2, RV1.3
unnamed: Q10.2 (E), R29.1
unnamed: Q10.1 (B), R30.2, R39.1
unnamed: Q5.2 (E), R37.1

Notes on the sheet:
PSU switched voltage divider
ESD protection
Undervoltage lockout
Place C6, C7 close to V3 and VCC pins
Route differentially, use guard tracks
copied from NodeMCU_v1
During boot: -GPIO15 must be kept low -GPIO2 must be kept high -GPIO0 HIGH -> RUN MODE, LOW -> FLASH MODE -Use GPIO16 for wake up from deep sleep.
Crystal only for CH340G, do not populate Y1, C3, C4 for CH340B. Place close to IC, use guard tracks.
Reverse polarity protection

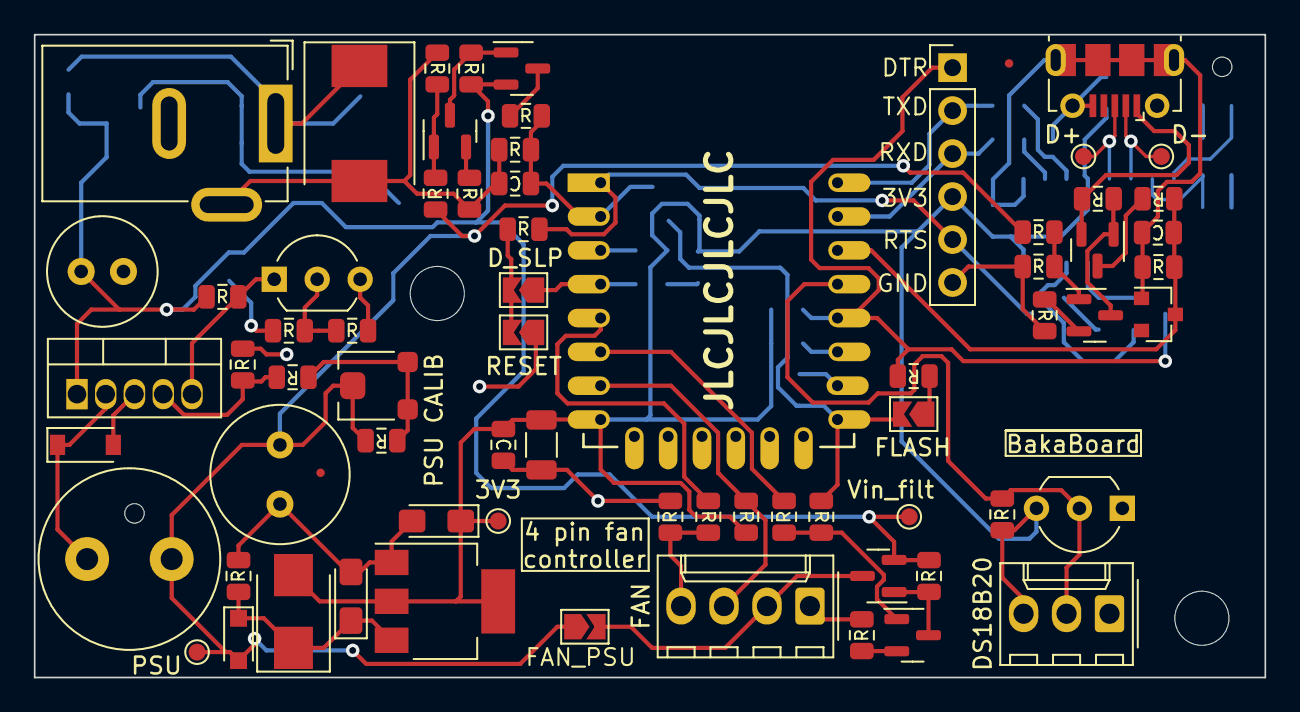
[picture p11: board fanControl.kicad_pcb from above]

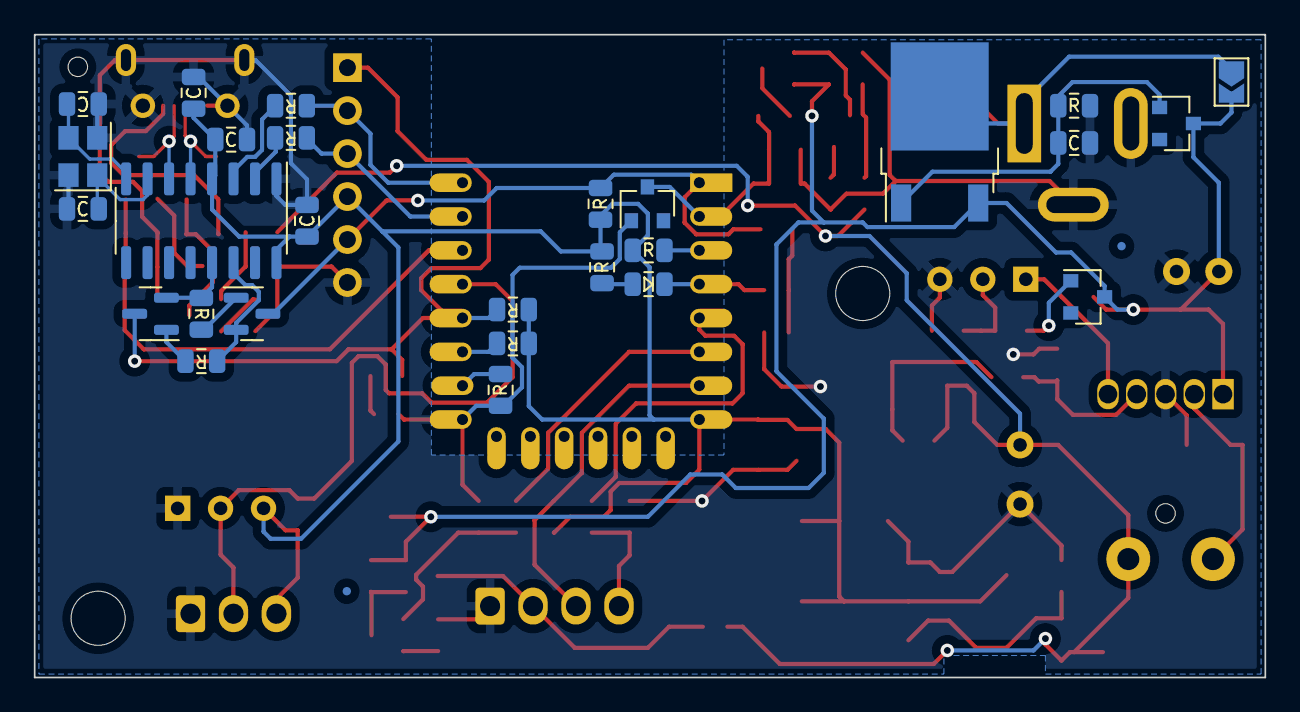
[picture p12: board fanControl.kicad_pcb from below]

Board: 2 copper layers, 72.8 x 38.0 mm, 104 parts (29 on the bottom side), 54 nets.

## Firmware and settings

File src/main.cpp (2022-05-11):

/*!
*   @link https://github.com/cyberponk/PWM_Signal_Analyzer_for_Arduino/blob/master/PWM_Signal_Analyzer_for_Arduino.ino
*
*   @note to enable ArduinOTA through Windows Firewall, temporarily enable "Display a notification to the user when a program is blocked from receiving inbound connections." and allow there.
*   Trying to chase down the python executable is messy otherwise.
*
*
*   @link ESP-12E pinout https://github.com/r00tGER/NodeMCU-ESP12E-pinouts
*/

#define _TASK_TIMECRITICAL

#include <Arduino.h>
#include <ESP8266WiFi.h>
#include <ESP8266WiFiMulti.h>
#include <ESP8266mDNS.h>
#include <ArduinoOTA.h>
#include <OneWire.h>
#include <DallasTemperature.h>
#include <TaskScheduler.h>
#include <ModbusIP_ESP8266.h>
#include "secrets.h"
#include <ESP_EEPROM.h>
#include <ArduinoJson.h>

/*! @brief how to receive variables from platformio.ini
*   @link https://community.platformio.org/t/setting-variables-in-code-using-build-flags/17167/5
*/
#define ST(A) #A
#define STR(A) ST(A)

#define LED_ON 0x00
#define LED_OFF 0x01

constexpr uint32_t BAUDRATE = 9600;
constexpr uint32_t PWMfreq = 25000;
constexpr uint8_t rpmPin = 13;      //GPIO13
constexpr uint8_t pwmPin = 14;      //GPIO14
constexpr uint8_t onewireBUS = 4;   //GPIO4
constexpr uint8_t PowEn = 12;       //GPIO12
constexpr uint8_t USBpin = 5;       //GPIO5
constexpr uint8_t Vmon = A0;        //ADC
constexpr uint8_t resolution = 9;
constexpr unsigned long numRegs = 12;
constexpr uint8_t slaveID = 1;
constexpr uint16_t RPMcalcPeriodMS = 400;
const uint16_t port = atoi(STR(PORT));
const char default_hostname[] = STR(MDNS_NAME);
constexpr size_t hostname_length = 16;

String inputSerialString;
bool serialReady = false;
bool serialStreamStarted = false;
static unsigned long lastRefreshTime_Serial = 0;
uint16_t buff_size = 512;
constexpr uint16_t serial_timeout_ms = 500;

volatile uint8_t halfRevs = 0;
uint16_t pwm = 0;
uint16_t setPoint_RPM = 0;
uint16_t voltage = 0;
char mDNS_name[hostname_length];
bool USBstate = false;
bool voltageEnable = false;
bool safeMode = true;
float temperature = 0;
DeviceAddress tempAddr;

struct EEPROM_struct {
    bool fan_psu = true;   //1 byte
    bool USB_en = false;    //1 byte
    float K_p = 1.0;    //2 bytes
    float K_i = 1.0;    //2 bytes
    float K_d = 0.1;    //2 bytes
    float cal_a = 1.0;    //4 bytes
    float cal_b = 0.0;    //4 bytes
    float nom_vol;  //4 bytes
    char hname[hostname_length]; //16 bytes
    uint16_t t_curve[3][2];
} eepromVar;

struct Kalman {
    private:
    float Pc = 0.0;
    float G = 0.0;
    float P = 1.3;
    float Xp = 0.0;
    float Zp = 0.0;
    float Xe = 0.0;

    public:
    float varMeas = 1;  // variance determined using excel and reading samples of raw sensor data
    float varProcess = 1e-2;

    float addMeasurement(float meas) {
        Pc = P + varProcess;
        G = Pc/(Pc + varMeas);    // kalman gain
        P = (1-G)*Pc;
        Xp = Xe;
        Zp = Xp;
        Xe = G*(meas-Zp)+Xp;   // the kalman estimate of the sensor voltage

        return Xe;
    }
} RPMfilter;

//! @link https://forum.arduino.cc/t/pid-self-balancing-robot/626526
struct PIDcontroller {
    private:
    unsigned long previousTime = 0;
    uint16_t *setPoint;
    int lastError, cumError;

    public:
    float Kp;
    float Ki;
    float Kd;

    void init (uint16_t* _setPoint) {
        setPoint = _setPoint;
    }

    uint16_t compute(uint16_t input, unsigned int elapsedTime) {
        int error = *setPoint - input;
        cumError += error * ((float)elapsedTime/1000);
        float rateError = (error - lastError) / ((float)elapsedTime/1000);

        int16_t output = Kp * error + Ki * cumError + Kd * rateError;

        lastError = error;

        output = output < 0 ? 0 : output;
        output = output > 1023 ? 1023 : output;

        if (output == 0 && *setPoint != 0)
            output = 20;

        return output;
    }
} pid;

IRAM_ATTR void rpmISR();
void calculateRPM_callback();
void measureTemp_callback();
void measureVoltages_callback();
void USBsense_callback();
void POWenable_callback();
void setRPM_callback();
void setup_wifi(const wifiList* APlist, const size_t len);
void setup_OTA();
void handleSerial_callback();
void serialWatchdog_callback();
void serialDisable_callback();
void parseSerial();
void printEEPROM();

OneWire oneWire(onewireBUS);
DallasTemperature ds(&oneWire);
ESP8266WiFiMulti wifiMulti;
ModbusIP modbus;
Scheduler ts;
DynamicJsonDocument dataJsonBuffer(buff_size);

Task calculateRPM(RPMcalcPeriodMS, TASK_FOREVER, &calculateRPM_callback);
Task measureTemp(5000, TASK_FOREVER, &measureTemp_callback);
Task measureVoltages(250, TASK_FOREVER, &measureVoltages_callback);
Task USBsense(500, TASK_FOREVER, &USBsense_callback);
Task POWenable(250, TASK_FOREVER, &POWenable_callback);
Task setRPM(1000, TASK_FOREVER, &setRPM_callback);
Task handleSerial(100, TASK_FOREVER, &handleSerial_callback);
Task serialWatchdog(50, TASK_FOREVER, &serialWatchdog_callback);
Task disableSerial(120000L, TASK_ONCE, &serialDisable_callback);

void setup() {
    pinMode(LED_BUILTIN, OUTPUT);
    digitalWrite(LED_BUILTIN, LED_ON);
    pinMode(rpmPin, INPUT);
    pinMode(Vmon, INPUT);
    pinMode(USBpin, INPUT);
    pinMode(PowEn, OUTPUT);
    pinMode(pwmPin, OUTPUT);
    analogWriteFreq(PWMfreq);
    analogWriteResolution(10);  /*! @link https://github.com/esp8266/Arduino/pull/7456 */
    analogWrite(pwmPin, pwm);
    attachInterrupt(digitalPinToInterrupt(rpmPin), rpmISR, CHANGE);
    inputSerialString.reserve(buff_size);

    Serial.begin(9600);

    EEPROM.begin(sizeof(EEPROM_struct));
    ts.init();

    if (EEPROM.percentUsed() >= 0) {
        EEPROM.get(0, eepromVar);
        printEEPROM();
        memcpy(mDNS_name, eepromVar.hname, hostname_length);

        ts.addTask(calculateRPM);
        ts.addTask(setRPM);
        //ts.addTask(disableSerial);
        if (eepromVar.USB_en)
            ts.addTask(USBsense);
        if (!eepromVar.fan_psu)
            ts.addTask(POWenable);
    }
    else {
        Serial.println("Error EEPROM not initialised. Entering calibration mode");
        memcpy(mDNS_name, default_hostname, hostname_length);
    }
    ts.addTask(measureVoltages);
    ts.addTask(handleSerial);
    ts.addTask(serialWatchdog);
    ts.enableAll();

    setup_wifi(APlist, APlen);
    setup_OTA();
    MDNS.begin(mDNS_name);

    modbus.server();
    for (size_t i = 0; i < numRegs; i++)
        modbus.addHreg(i);
    modbus.Hreg(3, pwm);

    //init PID controller for fan RPM
    pid.init(&setPoint_RPM);
    pid.Kp = eepromVar.K_p;
    pid.Ki = eepromVar.K_i;
    pid.Kd = eepromVar.K_d;
    modbus.Hreg(0, setPoint_RPM);

    modbus.Hreg(5, pid.Kp * 1000);
    modbus.Hreg(6, pid.Ki * 1000);
    modbus.Hreg(7, pid.Kd * 1000);
    modbus.Hreg(9, 2);

    ds.begin();
    if (ds.getDeviceCount() == 1) {
        ds.getAddress(tempAddr, 0);
        ds.setResolution(tempAddr, resolution);
        ds.requestTemperaturesByAddress(tempAddr);
        ds.setWaitForConversion(false); //enable async operation
        ts.addTask(measureTemp);
        measureTemp.enable();
    }
    digitalWrite(LED_BUILTIN, LED_OFF);
}

void loop() {
    ts.execute();

    wifiMulti.run();
    ArduinoOTA.handle();
    modbus.task();
    yield();
}

void handleSerial_callback() {
    while (Serial.available()) {
        char c = Serial.read();

        if (inputSerialString.length() == buff_size) {
            inputSerialString = F("");
            serialReady = false;
            serialStreamStarted = false;
            Serial.println("ERROR: Serial buffer overflow.");
            return;
        }
        if (c == '{') {
            serialStreamStarted = true;
            lastRefreshTime_Serial = millis();
        }

        if (serialStreamStarted) {
            if (c == '}') {
                inputSerialString += c;
                serialReady = true;
                serialStreamStarted = false;
            }
        else
            inputSerialString += c;
        }
    }

    if (serialReady) {
        parseSerial();
        inputSerialString = F("");
        serialReady = false;
    }

    return;
}

void serialWatchdog_callback() {
  if (serialStreamStarted && millis() >= lastRefreshTime_Serial + serial_timeout_ms) {
        Serial.println("Serial timeout");
        inputSerialString = F("");
		serialReady = false;
        serialStreamStarted = false;
    }
}

void serialDisable_callback() {
    handleSerial.disable();
    serialWatchdog.disable();
    return;
}

void parseSerial() {
    dataJsonBuffer.clear();

    DeserializationError err = deserializeJson(dataJsonBuffer, inputSerialString);
    if (err) {
        Serial.println(String(F("DESERIALIZATION failed with code ")) += err.c_str());
        return;
    }

    if (dataJsonBuffer.containsKey("fan_psu")) {
        eepromVar.fan_psu = dataJsonBuffer["fan_psu"];
    }
    if (dataJsonBuffer.containsKey("USB_en")) {
        eepromVar.USB_en = dataJsonBuffer["USB_en"];
    }
    if (dataJsonBuffer.containsKey("K_p")) {
        pid.Kp = dataJsonBuffer["K_p"];
        eepromVar.K_p = pid.Kp;
        modbus.Hreg(5, pid.Kp * 1000);
    }
    if (dataJsonBuffer.containsKey("K_i")) {
        pid.Ki = dataJsonBuffer["K_i"];
        eepromVar.K_i = pid.Ki;
        modbus.Hreg(6, pid.Ki * 1000);
    }
    if (dataJsonBuffer.containsKey("K_d")) {
        pid.Kd = dataJsonBuffer["K_d"];
        eepromVar.K_d = pid.Kd;
        modbus.Hreg(7, pid.Kd * 1000);
    }
    if (dataJsonBuffer.containsKey("cal_a")) {
        eepromVar.cal_a = dataJsonBuffer["cal_a"];
    }
    if (dataJsonBuffer.containsKey("cal_b")) {
        eepromVar.cal_b = dataJsonBuffer["cal_b"];
    }
    if (dataJsonBuffer.containsKey("nom_vol")) {
        eepromVar.nom_vol = dataJsonBuffer["nom_vol"];
    }
    if (dataJsonBuffer.containsKey("hname")) {
        String _hostname = dataJsonBuffer["hname"];
        if (_hostname.length() <= hostname_length && _hostname.length() > 0) {
            _hostname.toCharArray(eepromVar.hname, _hostname.length() + 1);
        }
    }
    if (dataJsonBuffer.containsKey("t_curve")) {
        for(int i = 0; i < 3; i++) {
            for(int j = 0; j < 2; j++) {
                eepromVar.t_curve[i][j] = dataJsonBuffer["t_curve"][i][j];
            }
        }
    }

    EEPROM.put(0, eepromVar);
    EEPROM.commit();
    EEPROM.get(0, eepromVar);
    printEEPROM();
}

void printEEPROM() {
    Serial.print("EEPROM data read, fan_PSU - ");
    Serial.println(eepromVar.fan_psu);
    Serial.print("EEPROM data read, USB_en - ");
    Serial.println(eepromVar.USB_en);
    Serial.print("EEPROM data read, K_p - ");
    Serial.println(eepromVar.K_p, 3);
    Serial.print("EEPROM data read, K_i - ");
    Serial.println(eepromVar.K_i, 3);
    Serial.print("EEPROM data read, K_d - ");
    Serial.println(eepromVar.K_d, 3);
    Serial.print("EEPROM data read, cal_a - ");
    Serial.println(eepromVar.cal_a, 6);
    Serial.print("EEPROM data read, cal_b - ");
    Serial.println(eepromVar.cal_b, 6);
    Serial.print("EEPROM data read, nom_vol - ");
    Serial.println(eepromVar.nom_vol, 2);
    Serial.print("EEPROM data read, hostname - ");
    for (uint16_t i = 0; i < hostname_length; i++)
        Serial.print(eepromVar.hname[i]);
    Serial.println("");
    Serial.print("EEPROM data read, t_curve - ");
    for(int i = 0; i < 3; i++) {
        Serial.print("[");
            for(int j = 0; j < 2; j++) {
                Serial.print(eepromVar.t_curve[i][j]);
                if (j==0) Serial.print(",");
            }
        Serial.print("]");
    }
    Serial.println("");
    return;
}

void setRPM_callback() {
    if (eepromVar.fan_psu == false && voltageEnable == false) {
        setPoint_RPM = 0;
        modbus.Hreg(0, setPoint_RPM);
        return;
    }

    if (eepromVar.USB_en == true && USBstate == false) {
        setPoint_RPM = 0;
        modbus.Hreg(0, setPoint_RPM);
        return;
    }

    if (temperature < eepromVar.t_curve[0][0]) {
        setPoint_RPM = eepromVar.t_curve[0][1];
        modbus.Hreg(0, setPoint_RPM);
        return;
    }
    if (temperature < eepromVar.t_curve[1][0]) {
        setPoint_RPM = eepromVar.t_curve[1][1];
        modbus.Hreg(0, setPoint_RPM);
        return;
    }
    if (temperature >= eepromVar.t_curve[1][0] && temperature < eepromVar.t_curve[2][0]) {
        uint16_t lin_scaler = (eepromVar.t_curve[2][1] - eepromVar.t_curve[1][1]) / (eepromVar.t_curve[2][0] - eepromVar.t_curve[1][0]);
        setPoint_RPM = eepromVar.t_curve[1][1] + (temperature - eepromVar.t_curve[1][0]) * lin_scaler;
        modbus.Hreg(0, setPoint_RPM);
        return;
    }
    if (temperature >= eepromVar.t_curve[2][0]) {
        setPoint_RPM = eepromVar.t_curve[2][1];
        modbus.Hreg(0, setPoint_RPM);
        return;
    }
}

IRAM_ATTR void rpmISR() {
    halfRevs++;
}

void measureTemp_callback() {
    temperature = ds.getTempC(tempAddr);
    modbus.Hreg(4, (temperature * 1000.0));
    ds.requestTemperatures();
    return;
}

void calculateRPM_callback() {
    uint8_t _revs = halfRevs;
    halfRevs = 0;
    float rpm;              //TODO shouldn't be float
    uint16_t deltaT = RPMcalcPeriodMS + calculateRPM.getStartDelay();

    rpm = (_revs / ((float)deltaT / 1000.0)) * 60.0 / 4;
    modbus.Hreg(2, rpm);    //raw RPM
    rpm = RPMfilter.addMeasurement(rpm);
    modbus.Hreg(1, rpm);    //filtered RPM

    pid.Kp = (float)modbus.Hreg(6) / 1000;
    pid.Ki = (float)modbus.Hreg(7) / 1000;
    pid.Kd = (float)modbus.Hreg(8) / 1000;

    pwm = pid.compute(rpm, deltaT);
    analogWrite(pwmPin, pwm);
    modbus.Hreg(3, pwm);
}

void measureVoltages_callback() {
    int val = analogRead(Vmon);
    val = eepromVar.cal_a * val + eepromVar.cal_b;
    voltage = val;
    modbus.Hreg(10, voltage);
    return;
}

void USBsense_callback() {
    USBstate = digitalRead(USBpin);
    modbus.Hreg(9, USBstate);
    return;
}

//! @note Check if voltage is whithin 10% of nominal voltage. nom_vol needs to be multipled by 100 because voltage is stored as integer.
void POWenable_callback() {
    if(voltage > (eepromVar.nom_vol * 0.9 * 100.0) && voltage < (eepromVar.nom_vol * 1.1 * 100)) {
        voltageEnable = true;
        digitalWrite(PowEn, voltageEnable);
        modbus.Hreg(8, voltageEnable);
        return;
    }
    voltageEnable = false;
    digitalWrite(PowEn, voltageEnable);
    modbus.Hreg(8, voltageEnable);
    return;
}

void setup_wifi(const wifiList* APs, const size_t len) {
	delay(10);

	//settings stolen from Tasmota, supposed to increase reliablity
	WiFi.persistent(false);
	WiFi.disconnect(true);
	delay(200);
	WiFi.mode(WIFI_STA);

    for(uint8_t i = 0; i < len; i++)
       wifiMulti.addAP(APs[i].ssid, APlist[i].psk);

    //! Wait for the Wi-Fi to connect: scan for Wi-Fi networks, and connect to the strongest of the networks above
	Serial.println();
	Serial.print("Adding SSIDs from the list and connecting to the strongest one.");

	while (wifiMulti.run() != WL_CONNECTED)
        delay(500);

	randomSeed(micros());
	WiFi.hostname(mDNS_name);

	Serial.println();
	Serial.println("WiFi connected");
    Serial.print("SSID: ");
    Serial.print(WiFi.SSID());
	Serial.println(" IP address: ");
	Serial.println(WiFi.localIP());

    return;
}

/*! OTA
*   @url: https://community.platformio.org/t/arduino-ota-on-esp8266/11823/3
*/
void setup_OTA() {
	ArduinoOTA.onStart([]() {
		String type;
		if (ArduinoOTA.getCommand() == U_FLASH)
			type = "sketch";
		else
		    type = "filesystem";
		//! @note if updating FS this would be the place to unmount FS using FS.end()
		Serial.println("Start updating " + type);
	});

    ArduinoOTA.setPort(port);
	ArduinoOTA.setPasswordHash(pwHash);

	ArduinoOTA.onEnd([]() {
		Serial.println("\nEnd");
	});

	ArduinoOTA.onProgress([](unsigned int progress, unsigned int total) {
		Serial.printf("Progress: %u%%\r\n", (progress / (total / 100)));
	});

	ArduinoOTA.onError([](ota_error_t error) {
		Serial.printf("Error[%u]: ", error);
		if (error == OTA_AUTH_ERROR)
		    Serial.println("Auth Failed");
		else if (error == OTA_BEGIN_ERROR)
		    Serial.println("Begin Failed");
		else if (error == OTA_CONNECT_ERROR)
            Serial.println("Connect Failed");
		else if (error == OTA_RECEIVE_ERROR)
		    Serial.println("Receive Failed");

		else if (error == OTA_END_ERROR)
		    Serial.println("End Failed");
		});

	ArduinoOTA.begin();
}

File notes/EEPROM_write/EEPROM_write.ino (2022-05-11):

// Example use of ESP_EEPROM library for ESP8266
//
// Normally writing to the 'emulated' EEPROM on ESP8266 requires an erase of the flash page used to hold
// the EEPROM data followed by a re-write of the changed data.
// The erasure takes a significant amount of time (10s of ms) and during this time
// interrupts must be blocked.
// In some cases this interferes with the sketch operation (e.g. it produces a noticeable
// blackout/flash for any PWM controlled lights as ESP8266 PWM relies on interrupts)
//
// The ESP_EEPROM library writes each new version of the EEPROM data to a new area until flash
// is full and so avoids wiping flash until necessary
//
// It's best for use when there are only a few things to save in EEPROM
// (i.e. total the size of the saved info is much smaller than the available flash size)
//

#include <ESP_EEPROM.h>

const int BLUE_LED_PIN = 2;

// The neatest way to access variables stored in EEPROM is using a structure
#pragma pack(push, 1)
struct EEPROM_struct {
    bool fan_psu;   //1 byte
    bool USB_en;    //1 byte
    float K_p;      //2 bytes
    float K_i;      //2 bytes
    float K_d;      //2 bytes
    float cal_a;    //4 bytes
    float cal_b;    //4 bytes
    float nom_vol;  //4 bytes
    char hname[16] = "fanControl_table"; //16 bytes
    uint16_t t_curve[3][2] = {{25,0}, {30, 500}, {40, 1500}};
} eepromVar, eepromVar2;
#pragma pack(pop)

void setup() {
  // Remember to set your serial monitor to 74880 baud
  // This odd speed will show ESP8266 boot diagnostics too
  Serial.begin(9600);
  Serial.println();

  // Set up the initial (default) values for what is to be stored in EEPROM
  eepromVar.fan_psu = false;
  eepromVar.USB_en = true;
  eepromVar.K_p = 1.0;
  eepromVar.K_i = 1.0;
  eepromVar.K_d = 0.1;
  eepromVar.cal_a = 4.571274;
  eepromVar.cal_b = - 22.811258;
  eepromVar.nom_vol = 12.0;
//  eepromVar.hname = "fanControl_table";
//   eepromVar.t_curve = {{25,0}, {30, 500}, {40, 1500}};
//   eepromVar.t_curve[0][0] = 25;
//   eepromVar.t_curve[0][1] = 0;
//   eepromVar.t_curve[1][0] = 30;
//   eepromVar.t_curve[1][1] = 500;
//   eepromVar.t_curve[2][0] = 40;
//   eepromVar.t_curve[2][1] = 1500;

  // All the library functions are accessed via the EEPROM object created when
  // you include the library header ESP_EEPROM.h

  // The library needs to know what size you need for your EEPROM variables
  // Using a structure makes this easy.

  // The begin() call will find the data previously saved in EEPROM if the same size
  // as was previously committed. If the size is different then the EEEPROM data is cleared.
  // Note that this is not made permanent until you call commit();
  EEPROM.begin(sizeof(EEPROM_struct));

  // Check if the EEPROM contains valid data from another run
  // If so, overwrite the 'default' values set up in our struct
  /*if(EEPROM.percentUsed()>=0) {
    EEPROM.get(0, eepromVar1);
    eepromVar1.anInteger++;     // make a change to our copy of the EEPROM data
    Serial.println("EEPROM has data from a previous run.");
    Serial.print(EEPROM.percentUsed());
    Serial.println("% of ESP flash space currently used");
  } else {
    Serial.println("EEPROM size changed - EEPROM data zeroed - commit() to make permanent");
  }*/

  //
  // (some code that might change the EEPROM data)
  //

  // set the EEPROM data ready for writing
  EEPROM.put(0, eepromVar);

  // write the data to EEPROM
  boolean ok = EEPROM.commit();
  Serial.println((ok) ? "Commit OK" : "Commit failed");

  // Get EEPROM data into our local copy
  // For this example, a different struct variable is used 
  EEPROM.get(0, eepromVar2);

  Serial.print("EEPROM data read, fan_PSU - ");
  Serial.println(eepromVar.fan_psu);
  Serial.print("EEPROM data read, USB_en - ");
  Serial.println(eepromVar.USB_en);
  Serial.print("EEPROM data read, K_p - ");
  Serial.println(eepromVar.K_p, 3);
  Serial.print("EEPROM data read, K_i - ");
  Serial.println(eepromVar.K_i, 3);
  Serial.print("EEPROM data read, K_d - ");
  Serial.println(eepromVar.K_d, 3);
  Serial.print("EEPROM data read, cal_a - ");
  Serial.println(eepromVar.cal_a, 6);
  Serial.print("EEPROM data read, cal_b - ");
  Serial.println(eepromVar.cal_b, 6);
  Serial.print("EEPROM data read, nom_vol - ");
  Serial.println(eepromVar.nom_vol, 2);
  Serial.print("EEPROM data read, hostname - ");
  for (int i = 0; i < hostname_length; i++)
      Serial.print(eepromVar.hname[i]);
  Serial.println("");
  Serial.print("EEPROM data read, t_curve - ");
  for(int i = 0; i < 3; i++) {
      Serial.print("[");
          for(int j = 0; j < 2; j++) {
              Serial.print(eepromVar.t_curve[i][j]);
              if (j==0) Serial.print(",");
          }
      Serial.print("]");
  }
  Serial.println("");
}


void loop() {
  // do nothing
}

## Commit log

2021-08-30 added PID control
2021-10-22 PID tuning
2021-10-26 PWM set to 10bit
2022-02-05 PCB file added
    [PSU.sch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]
2022-02-05 KiCad 6 migration
    [PSU.sch, fanControl.kicad_pcb, fanControl.kicad_sch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]
2022-02-06 LCSC BOM done
    [fanControl.csv, fanControl.kicad_pcb, fanControl.kicad_sch]
2022-04-12 before optocouplers
    [fanControl.kicad_pcb, fanControl.kicad_sch, fanControl_BOM.xlsx]
2022-05-06 added readme
    [fanControl_stock.xlsx, kalman_example.xlsx]
2022-05-07 calculation updates
    [ADC_calib.xlsx]
2022-05-09 EEPROM setup over serial PoC
    [fanControl_stock.xlsx]
2022-05-11 added PCB backup folder
